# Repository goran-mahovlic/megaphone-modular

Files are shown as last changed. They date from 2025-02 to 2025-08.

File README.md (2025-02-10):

# megaphone-r5-modular
Modularised MEGAphone Design

This project is being carried out with the support of the NLnet Foundation under: https://nlnet.nl/project/MEGA65-MVP/

The goal of this project is to push the MEGAphone forward towards a Minimum Viable Product (MVP) in a cost-effective way by modularising the PCB
allowing for faster development and lower development costs as a result. Also, the modularisation helps to work around supply-chain problems by
allowing the replacement of hard to source components, without requiring a full PCB redesign.  Those modules can also be manufactured much more easily
in a domestic setting, as there is less cumulative chance of messing something up.  Alternatively, they can be manufactured in modest sized batches
using PCB fabrication places like PCBWay, who also offer an assembly option.

The following sections outline the tasks and their current state of progress, where appropriate.

## Task 1: Development and testing of core simple cellular telephony and text messaging software

The software aspect of this project relates to the software required to control and interact with the hardware modules, as well as to perform basic telephony functionality.

## Task 2: Modularisation and testing of the PCB design

The major hardware stream of this project is focused on modularising the MEGAphone PCB, so that the modules can be iterated and/or manufactured independently. This is to support both users self-manufacturing, so that the complexity of the fabrication process can be greatly simplified, as well as to allow for much faster and, including ad-hoc response to future supply chain challenges. 

### 2.1 High-efficiency DC-DC converter module to power the various sub-systems

High-current and high-efficiency modules are required for the main FPGA, cellular modem, auxilliary communications module, LCD panel, and external speaker/bluetooth modules.  It is desirable to come up with a single module that can be reused several times for these purposes.  The cellular modems are likely to be the highest draw item, and according to https://ww1.microchip.com/downloads/en/Appnotes/ANLPS300-APID.pdf, they can draw upto around 2A at 3.3V, which is the voltage we will most likely use, since it allows a common voltage for many of our sub-systems.

It is unlikely that any other device on the system will consume more power than this, so our DC-DC modules need to support 2A.

A further requirement is that it must be buck-boost, as the LiFePO4 cells can go below 3.3V, but when charged are >3.3V.

Some possible parts to consider:

STBBJ3 https://www.st.com/en/power-management/stbb3j.html  (2A in buck mode, i.e., where VIN > 3.3V, but only 800mA in boost mode, i.e., where VIN < 3.3V). 5x4 grid array, without thermal pad. Shutdown and soft-start. "typical" efficiency of 94%
LTC3113 https://www.analog.com/media/en/technical-documentation/data-sheets/3113f.pdf (3A in buck mode, 1.5A in boost mode). "up to" 96% efficiency. Choice of grid array and TSSOP -- but with a concealled thermal pad on the underside, which is not easy to hand-solder. AU$20 each for TTSOP!

### 2.2 Low-energy power-management module to minimise energy consumption of device, especially in low-power modes

### 2.3 Battery management and energy harvesting module to allow USB-C, integrated solar panel and external 12/24V vehicle battery power sources, and efficient management of the integrated rechargeable battery

### 2.4 Cellular modem communications module, including SIM card module

### 2.5 Internal microphone and speaker module

### 2.6 External speaker and bluetooth headset interface module

### 2.7 Primary FPGA carrier module, leveraging off-the-shelf FPGA modules if at all possible

### 2.8 LCD panel interface module

### 2.9 Auxiliary communications module, e.g., LoRa, ultra-sonic, infra-red or mm wave

Low-cost LoRa devices based on the SX1262 look to be an option, using open-source software like this: https://github.com/beegee-tokyo/SX126x-Mesh-Network
The goal would be for the module to be able to autonomously participate in the mesh while the main process is off.  ESP32s can go into low power modes with <1mA consumption according to https://www.arrow.com/en/research-and-events/articles/esp32-power-consumption-can-be-reduced-with-sleep-modes, and the SX1262 uses only about 5mA to listen for packets, and perhaps 70mA when active, so this looks plausible. The SX1262 when transmitting can draw upto about 120mA according to https://semtech.my.salesforce.com/sfc/p/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

Thus the total power consumption of an auxilliary communications module (assuming we include an ESP32 in it, rather than using the power management FPGA to run the mesh) will be about 5mA while idle (~17mW) and upto ~200mA (~660mW).

### 2.10 Main carrier board and assembly, into which the various modules connect

## Task 3: Integration, Integration testing and remediation of the modules

Once the modules have been tested independently, this activity is focussed on testing the behaviour of the modules when connected to one another, including any VHDL/FPGA programming required to achieve this.

### 3.1 Requirements specification and analysis

### 3.2 Hardware integration and testing, including FPGA programming

### 3.3 Software integration and testing

### 3.4 Engage with and respond to security and accessibility audits

### 3.5 Remediation and contingency – for addressing any issues with the software and/or hardware components identified during the integration, and implementing or documenting appropriate solutions and/or work-arounds as appropriate

## Task 4: Preparation of Prototype Units

This activity focuses on taking the integrated hardware and software modules, and building a small number of units that are alpha-quality prototypes.  The specific objective is that they be integrated into units that are suitable for developers to use to continue development of both hardware and software of the system.  These units may be somewhat larger than the final obtainable footprint, depending on the costs of designing and fabricating the housings/enclosures.  The limited budget prevents the engagement of industrial designers who would be required for the completion of design for manufacture. Instead, we anticipate that the enclosures will be relatively simple 3D printed designs.
The remediation budget line is to allow for adjustment to the case design, the fabricated case and/or any of the hardware modules, so that the prototypes can be assembled and be as functional as possible.

### 4.1 Case Design

### 4.2 Case Fabrication

### 4.3 Assembly

### 4.4 Remediation / Mitigation, e.g., of any fitment issues, whether by adjustment of the case, reworking of a module or other means.

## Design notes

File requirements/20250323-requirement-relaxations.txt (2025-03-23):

Relaxation of Requirement 2.1.2: Bluetooth host module support for keyboards and other HID peripherals. Downgrade from REQUIREMENT to DESIRABLE.
Impact: Bluetooth keyboards and other HID devices will not be usable.
Proposed: PGS
Assessed and approved: PGS

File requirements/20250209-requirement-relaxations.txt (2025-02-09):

Relaxation of Requirement 1.2.2.1: Maximum input voltage reduced from 40V to ~28V.
Impact: (1) 24V truck systems may peak out of range when alternator charging. (2) Some larger solar panels may be out of spec. However, given the ~30Wh battery size, this should not be a problem. Impact acceptable.
Proposed: PGS
Assessed and approved: PGS

Relaxation of Requirement 1.2.3.1: Minimum solar panel input voltage increased from 2V to 6V.
Impact: Some very small panels, especially those consisting of few cells in series, no longer in specification.  However, small panels (eg 55x70mm) are readily available with 6V MP voltages. Thus the impact is acceptable.
Proposed: PGS
Assessed and approved: PGS

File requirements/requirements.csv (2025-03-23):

Requirement | Description
Requirement 1.1.1 | "Integrated LiFePO4 or other similarly safe and robust chemistry battery cell."
Requirement 1.1.2 | "Battery capacity and idle power consumption combine to support a battery endurance of at least 1 week when idle."
Requirement 1.1.2.1 | "Integrated battery capacity of at least 30Wh."
Requirement 1.1.2.2 | "Idle power consumption below 175mW."
Requirement 1.2.1.1 | "The internal battery shall be chargeable via an integrated USB-C connector | ideally fast charging."
Requirement 1.2.1.2 | "Define module bay for USB-C charger + data module | large enough to fit the SparkFun module | as that looks to be the biggest | capable of delivering 20V @ 3A to the carrier board."
Requirement 1.2.1.3 | "Proof-of-concept charger module based on a given USB-C power delivery module (no need for data)."
Requirement 1.2.1.4 | "Power isolation mechanism to allow conflict-free operation of the USB-C and alternative power inputs to the MEGAphone (back-flow and over-voltage protection | for example)"
Requirement 1.2.2.1 | "Means of accepting (including connector) dirty DC power between ~9V and ~28V using a MPPT to maximise efficiency with a solar panel. (Varied 20250209)"
Requirement 1.2.3.1 | "Means of accepting DC power from integrated solar panel at input voltages of 6V to 20V with a MPPT. (Varied 20250209)"
Requirement 1.3.1 | "Power management processor that can control power to all other sub-systems | and itself have very low power consumption | ideally <10mW."
Requirement 1.3.2 | "Ability for power management processor to buffer communications when main processor is powered off."
Requirement 1.3.3 | "Galvanic isolation of communications lines between sub-systems that can be independently powered off | e.g. | using opto-isolators."
Requirement 1.3.4 | "A small module for galvanic isolation | so that this can be reused. "
Requirement 1.3.5 | "Implement UART connection between power control processor and the main FPGA via MEGA65 buffered UART interface. "
Requirement 1.3.6 | "Protect writing to the power control UART so that it can be done only from the Hypervisor."
Requirement 1.3.7 | "Implement Hypervisor calls to provide an API for applications to request power to be switched on and off."
Requirement 1.3.8 | "Implement register access to check battery state and charger status (i.e. | charging | discharging | which power source(s) are present)."
Requirement 1.4.1 | "High-efficiency DC switchable DC power supplies that can support various sub-systems with >=2A @ 3.3V or 5V (externally selectable) | with an efficiency of at least 90% in typical conditions when powered from a single cell LiFEPO4 battery (28.V - 3.2V)."
Requirement 1.4.2 | "LCD Panel Backlight power supply module (20V | 50mA | powered from VBAT | switchable via a single enable input pin) | unless incorporated into the solution to Requirement 3.3.1)."
Requirement 2.1.1 | "Bluetooth host module that can connect to headsets and other audio devices. Must support UART or I2C control | and audio interfaces that we can easily implement from the FPGA | such as I2S audio."
Desirable 2.1.2 | "Bluetooth host module support for keyboards and other HID peripherals."
Requirement 2.2.1 | "Cellular Module Carrier board that can accept an industry standard industrial cellular modem | breaking out all pins from the connectors | and provides a SIM card slot."
Requirement 2.2.2 | "Create UART for cellular modem AT command interface to the MEGA65 buffered serial interface. This should keep output from cellular modem in a buffer until the application requests the next line or bunch of bytes | and require acknowledgement each time | to prevent loss of important messages."
Requirement 2.2.3 | "Allow Hypervisor to protect access to the cellular modem UART."
Requirement 2.2.4 | "Create Hypervisor API to request access to the cellular modem."
Requirement 2.3.1 | "Power-switched | galvanically isolated UART interface to a module bay that can accept an alternative communications module"
Requirement 2.3.2 | "A proof-of-concept module for the above that can accommodate some alternative communications module."
Requirement 3.1.1 | "One or more power-switchable MEMS microphones with power status indication."
Requirement 3.2.1 | "Audio CODEC or equivalent that has output channels for loud speaker (mono is ok) | 3.5mm audio output (stereo) ear piece | and input channel for 3.5mm microphone."
Requirement 3.3.1 | "Module to connect to industrial LCD panels of the type used in previous MEGAphone prototypes | large enough to allow for some variability in cable lengths and positions | for both DVGA and touch interface. Allow for either resistive or capacitive interfaces. Include appropriate LCD backlight driver and expose the PWM brightness control signal."
Requirement 3.3.2 | "Module bay to accept the LCD panel module."
Requirement 3.4.1 | "Module hosting a thumb-wheel potentiometer and an I2C potentiometer | with two pins to select I2C address of the module | and pads on the module to add the selection resistors if required."
Requirement 3.4.2 | "Module to accept D-pad"
Requirement 3.4.3 | "Module to accept push-button pairs"
Requirement 3.4.4 | "I2C I/O Expander to accept inputs from buttons and control LEDs"
Requirement 3.4.5 | "Slider switch module for input"
Desirable 3.4.6 | "Module for hosting e-ink display and recessed buttons"
Desirable 3.4.7 | "Module specification for hosting I2C sensors and peripherals"
Requirement 4.1.1 | "A100T or larger FPGA module SWaP and pin-compatible with the Trenz TE0725."
Requirement 4.2.1 | "Module bay that can power and host a FireAnt or similar FPGA module to control the power to all sub-systems | and interdict the communications between the main FPGA and sub-systems that require monitoring when the main FPGA is powerd off."
Desirable 4.3.1 | "Bay for Pi Compute Module 4"
Desirable 4.3.2 | "DVGA multiplexor to allow LCD panel to display either the MEGA65 or Pi display | on a pixel by pixel basis."
Desirable 4.3.3 | "Isolatable USB data connection between cellular modem and Pi."
Desirable 4.3.4 | "UART interface between Pi Compute Module and MEGA65 core."
Requirement 5.1.1 | "Main carrier board that connects all sub-systems together."
Requirement 5.1.2 | "Design a 3D-printable / CNC machinable case to contain the electronics package."
Requirement 6.1.1 | "Power control API on low-power FPGA to allow control of power to all sub-systems | including the main FPGA."
Requirement 6.1.2 | "Logic to activate power to the main FPGA based on relevant criteria (eg incoming call | user pressing power button etc)."
Requirement 6.1.3 | "UART interface between main and low-power FPGA module exposed via one of the MEGA65 buffered UART interfaces."
Requirement 6.1.4 | "MEGA65-side software that implements the power control API."
Requirement 6.2.1 | "Can initiate telephone calls via dialing or selecting a contact."
Requirement 6.2.2 | "Can accept incoming telephone calls | showing contact name when the caller matches an existing contact."
Requirement 6.2.3 | "Can list contacts."
Requirement 6.2.4 | "Can add a contact."
Requirement 6.2.5 | "Can edit a contact."
Requirement 6.2.6 | "Can delete a contact. "
Requirement 6.2.7 | "Incoming calls are indicated | even if the user is performing some other function (e.g. | OSD overlay or blinking LED)."
Requirement 6.3.1 | "Incoming SMS messages are indicated | even if the user is performing some other function (e.g. | OSD overlay or blinking LED)."
Requirement 6.3.2 | "SMS message can be composed and sent to a number or contact."
Requirement 6.3.3 | "SMS message can be received | and the corresponding contact indicated."
Desirable 6.3.4 | "SMS messages are logged | so that SMS conversation threads can be displayed."

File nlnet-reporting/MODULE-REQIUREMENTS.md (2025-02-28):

# Summary of Progress

During this tranch of activity, the full requirements for the MEGAphone Modular were derived and documented.
The derivation of the requirements can be found in this blog post:

https://c65gs.blogspot.com/2025/02/modular-megaphone-requirement.html

A collated table of the requirements can be found here:

https://github.com/MEGA65/megaphone-modular/blob/main/requirements/requirements.csv

# System Requirements Mapping to NLNet Milestones

For the specific requirements specification milestones claimed, the mapping between those milestones and the derived requirements is summarised below.

Note that for some modules, the requirements have ended up being quite short and succinct. This is a positive feature, enabled by the substantial work undertaken to understand the system, decompose it sensibly, and then distill the actual requirements (including a few desirable characteristics) of the system.

| NLnet Milestone | Requirement(s) of Relevance |
| --- | --- |
| 2.1.1 High-efficiency DC-DC converter module to power the various sub-systems | [1.4.1](https://github.com/MEGA65/megaphone-modular/blob/main/requirements/requirements.csv#L20) |
| 2.2.1 Low-energy power-management module to minimise energy consumption of device, especially in low-power modes | [1.1.2](https://github.com/MEGA65/megaphone-modular/blob/main/requirements/requirements.csv#L3), [1.1.2.2](https://github.com/MEGA65/megaphone-modular/blob/main/requirements/requirements.csv#L5), [4.2.1](https://github.com/MEGA65/megaphone-modular/blob/main/requirements/requirements.csv#L44), [6.1.1](https://github.com/MEGA65/megaphone-modular/blob/main/requirements/requirements.csv#L50), [6.1.3](https://github.com/MEGA65/megaphone-modular/blob/main/requirements/requirements.csv#L52) |
| 2.3.1 Battery management and energy harvesting module to allow USB-C, integrated solar panel and external 12/24V vehicle battery power sources, and efficient management of the integrated rechargeable battery | [1.2.1.1](https://github.com/MEGA65/megaphone-modular/blob/main/requirements/requirements.csv#L6), [1.2.1.2](https://github.com/MEGA65/megaphone-modular/blob/main/requirements/requirements.csv#L7), [1.2.1.3](https://github.com/MEGA65/megaphone-modular/blob/main/requirements/requirements.csv#L8), [1.2.1.4](https://github.com/MEGA65/megaphone-modular/blob/main/requirements/requirements.csv#L9), [1.2.2.1](https://github.com/MEGA65/megaphone-modular/blob/main/requirements/requirements.csv#L10), [1.2.3.1](https://github.com/MEGA65/megaphone-modular/blob/main/requirements/requirements.csv#L11), [1.3.1](https://github.com/MEGA65/megaphone-modular/blob/main/requirements/requirements.csv#L12), [1.3.2](https://github.com/MEGA65/megaphone-modular/blob/main/requirements/requirements.csv#L13) |
| 2.4.1 Cellular modem communications module, including SIM card module | [2.2.1](https://github.com/MEGA65/megaphone-modular/blob/main/requirements/requirements.csv#L26) |
| 2.5.1 Internal microphone and speaker module | [3.1.1](https://github.com/MEGA65/megaphone-modular/blob/main/requirements/requirements.csv#L31), [3.2.1](https://github.com/MEGA65/megaphone-modular/blob/main/requirements/requirements.csv#L32) |
| 2.6.1 External speaker and bluetooth headset interface module | [2.1.1](https://github.com/MEGA65/megaphone-modular/blob/main/requirements/requirements.csv#L24), [2.1.2](https://github.com/MEGA65/megaphone-modular/blob/main/requirements/requirements.csv#L25) |
| 2.7.1 Primary FPGA carrier module, leveraging off-the-shelf FPGA modules if at all possible | [4.1.1](https://github.com/MEGA65/megaphone-modular/blob/main/requirements/requirements.csv#L43) |
| 2.8.1 LCD panel interface module | [1.4.2](https://github.com/MEGA65/megaphone-modular/blob/main/requirements/requirements.csv#L21), [3.3.1](https://github.com/MEGA65/megaphone-modular/blob/main/requirements/requirements.csv#L33), [3.3.2](https://github.com/MEGA65/megaphone-modular/blob/main/requirements/requirements.csv#L34) |
| 2.9.1 Auxiliary communications module, e.g., LoRa, ultra-sonic, infra-red or mm wave: Requirement Specification | [2.3.1](https://github.com/MEGA65/megaphone-modular/blob/main/requirements/requirements.csv#L28), [2.3.2](https://github.com/MEGA65/megaphone-modular/blob/main/requirements/requirements.csv#L29) |
| 2.10.1 Main carrier board and assembly, into which the various modules connect | [3.2.1](https://github.com/MEGA65/megaphone-modular/blob/main/requirements/requirements.csv#L32), [3.4.2](https://github.com/MEGA65/megaphone-modular/blob/main/requirements/requirements.csv#L36), [3.4.3](https://github.com/MEGA65/megaphone-modular/blob/main/requirements/requirements.csv#L37), [3.4.4](https://github.com/MEGA65/megaphone-modular/blob/main/requirements/requirements.csv#L38), [3.4.5](https://github.com/MEGA65/megaphone-modular/blob/main/requirements/requirements.csv#L39), [3.4.7](https://github.com/MEGA65/megaphone-modular/blob/main/requirements/requirements.csv#L41), [5.1.1](https://github.com/MEGA65/megaphone-modular/blob/main/requirements/requirements.csv#L45) |

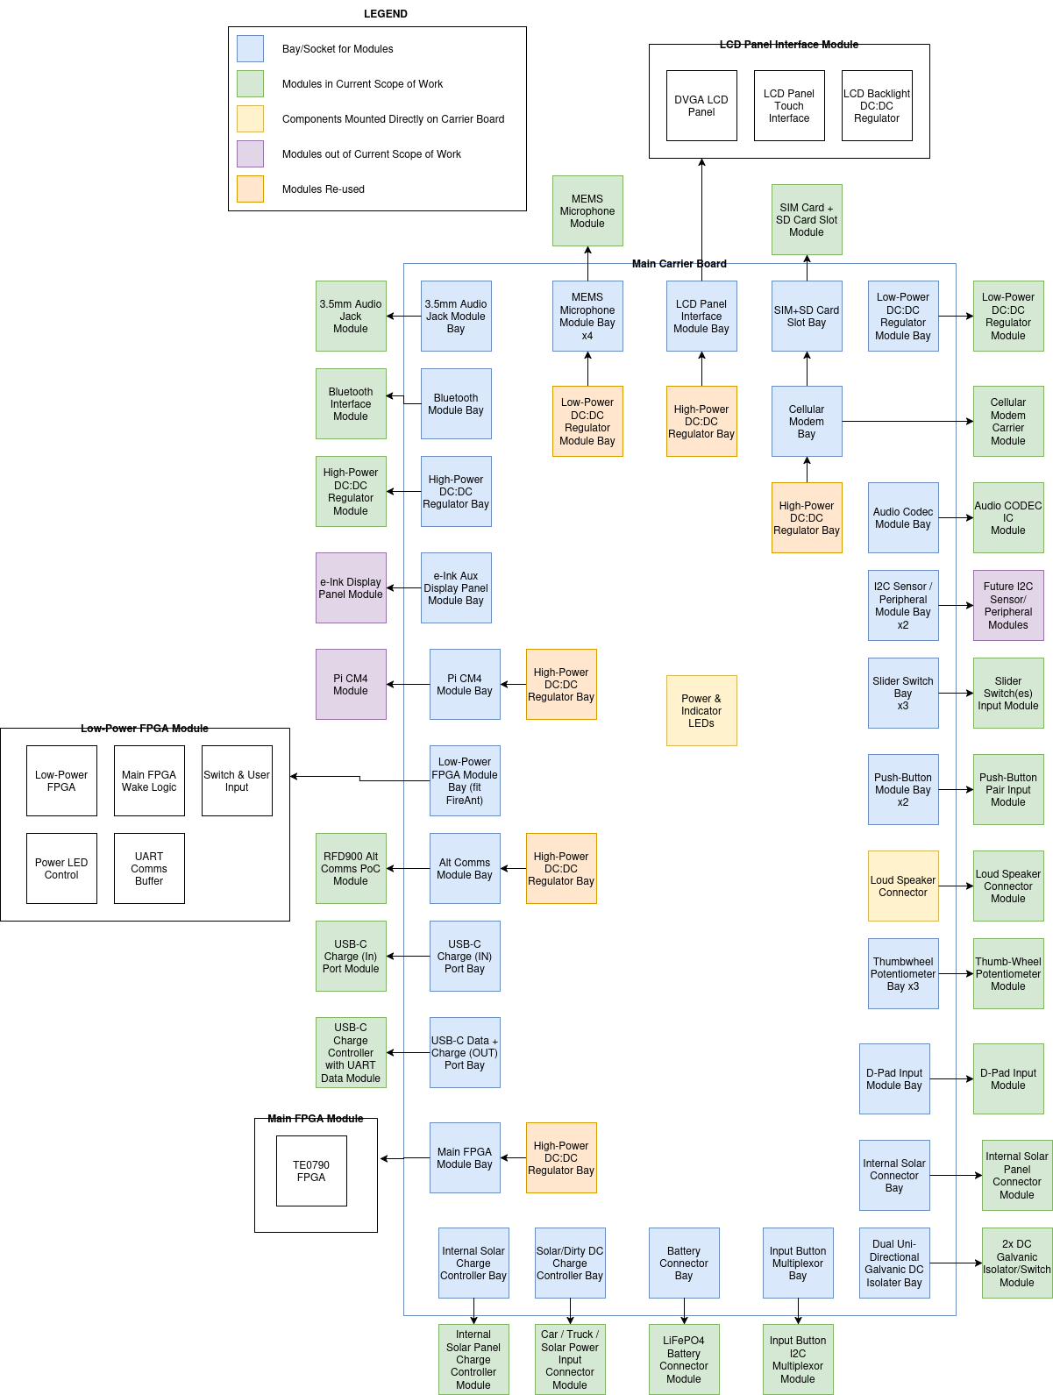
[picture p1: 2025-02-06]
diagrams/modular-megaphone-block-diagram.drawio.png

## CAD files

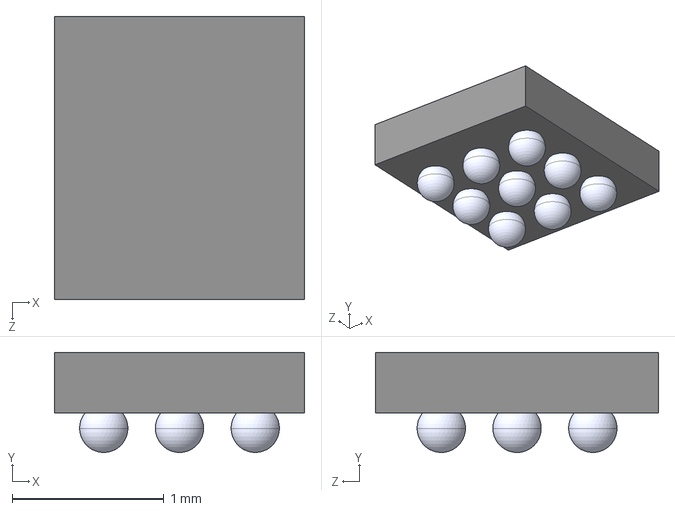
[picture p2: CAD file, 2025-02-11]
modules/audio-codec/ADP5301ACBZ-1-R7.step
1.65 x 0.66 x 1.87 mm

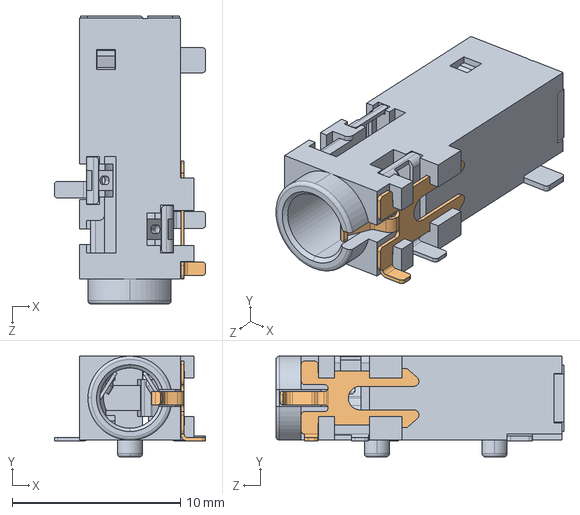
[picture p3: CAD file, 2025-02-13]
modules/audio-jack/SJ-43514-SMT-TR.step
9.00 x 6.00 x 17.1 mm

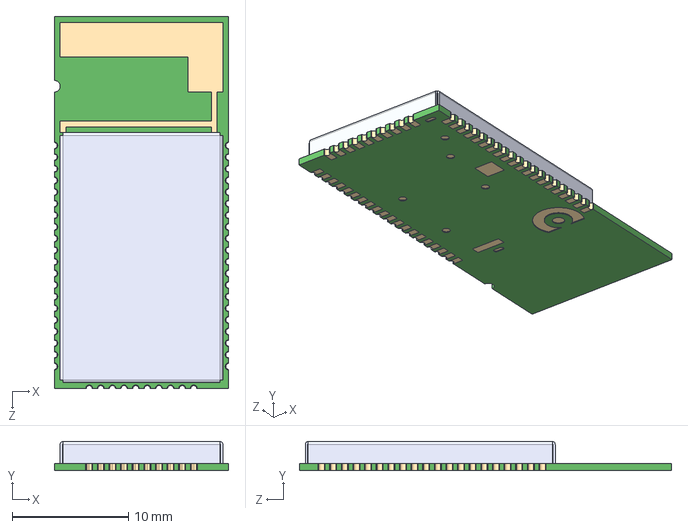
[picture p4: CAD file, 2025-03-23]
modules/bluetooth/footprints/BM83SM1-00AA.step
15.0 x 2.50 x 32.0 mm

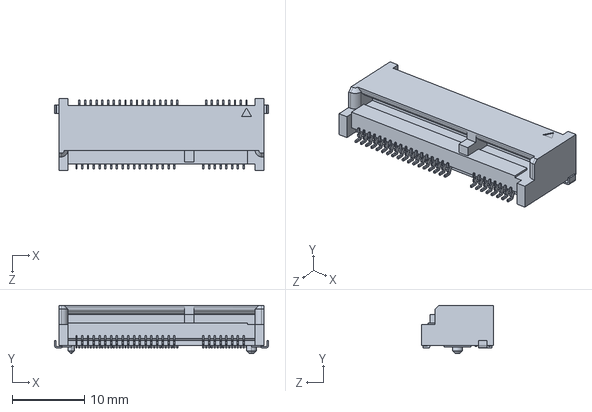
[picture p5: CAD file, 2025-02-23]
modules/cellular-modem/MM60-52B1-E1-R2 JAE Connector Division Proprietary.step
29.7 x 6.70 x 10.0 mm

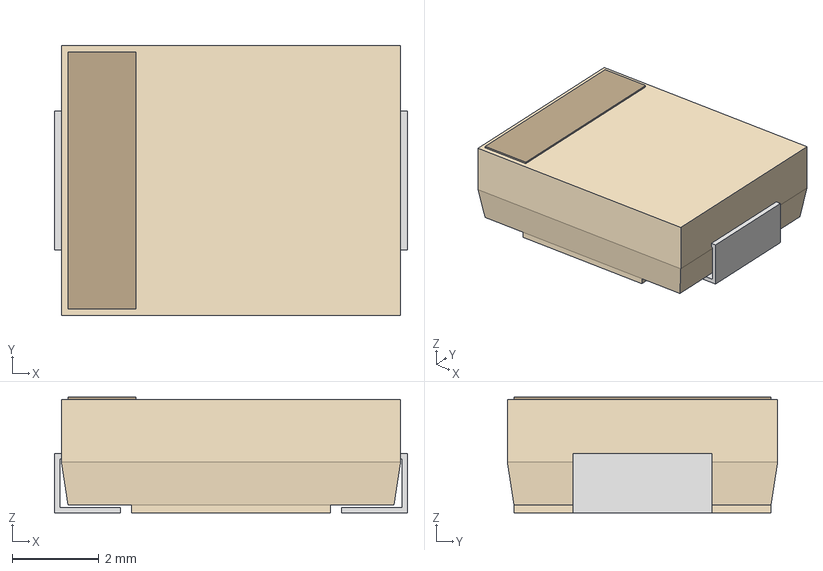
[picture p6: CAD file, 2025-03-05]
modules/input-power-selector/footprints/SMCJSeries_LTF.step
8.13 x 6.22 x 2.67 mm

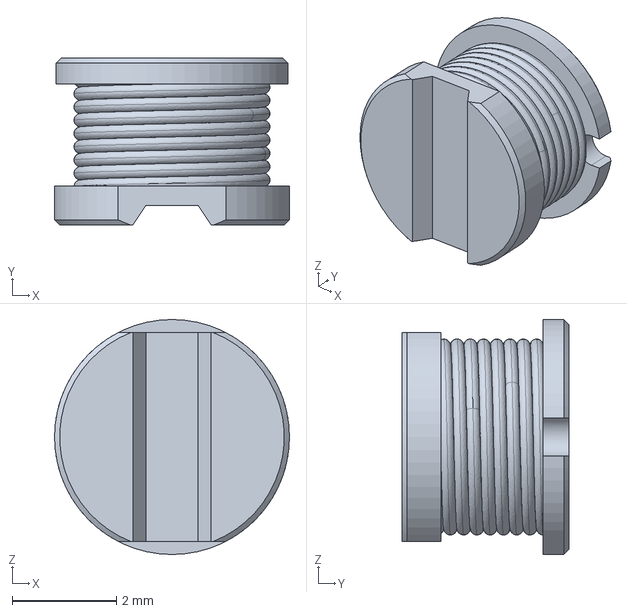
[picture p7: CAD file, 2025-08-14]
modules/lcd-panel/SDR0403-4R7ML.stp
4.50 x 3.20 x 4.50 mm

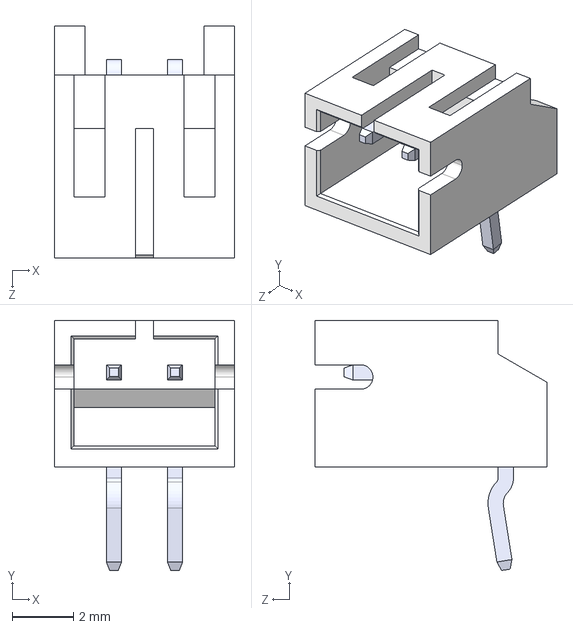
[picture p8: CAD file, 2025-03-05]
modules/solar-and-dc-connectors/footprints/S2B-PH-K-S.STEP
5.90 x 8.18 x 7.60 mm

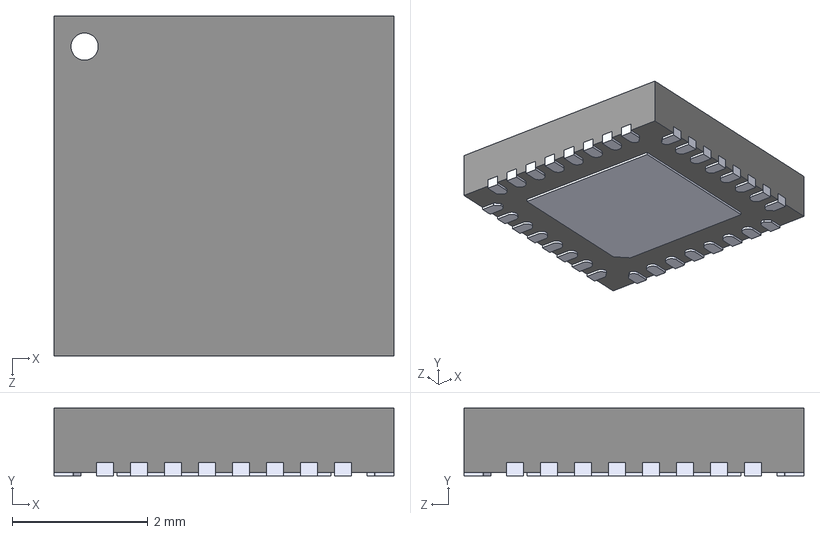
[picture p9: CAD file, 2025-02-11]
modules/audio-codec/TLV320AIC3110IRHBR.step
5.00 x 1.00 x 5.00 mm

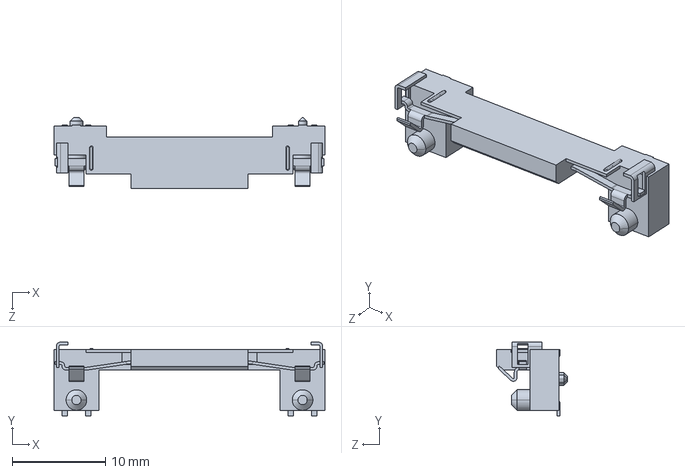
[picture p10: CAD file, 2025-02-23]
modules/cellular-modem/MM60-EZH059-B5-R2 JAE Connector Division Proprietary.step
29.0 x 7.90 x 7.60 mm

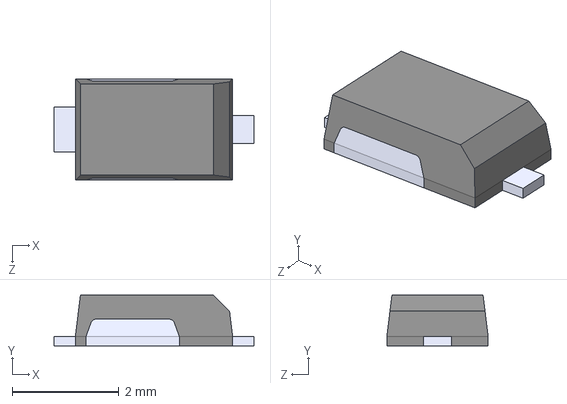
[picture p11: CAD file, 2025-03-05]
modules/input-power-selector/footprints/SMM4F24A-TR.step
3.75 x 0.95 x 1.90 mm

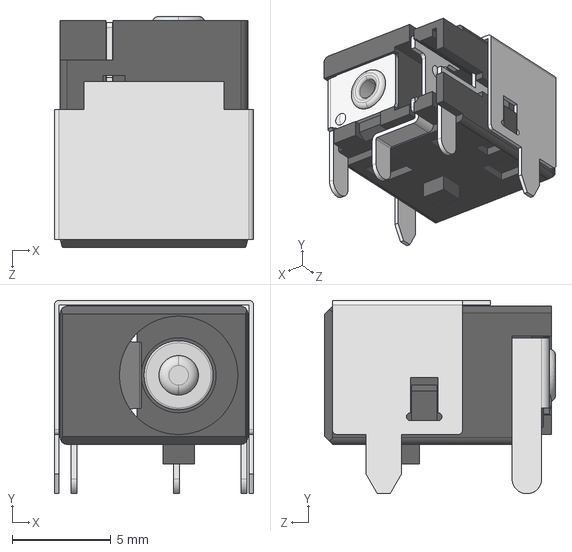
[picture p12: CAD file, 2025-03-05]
modules/solar-and-dc-connectors/footprints/54-00127.step
10.1 x 9.80 x 11.7 mm

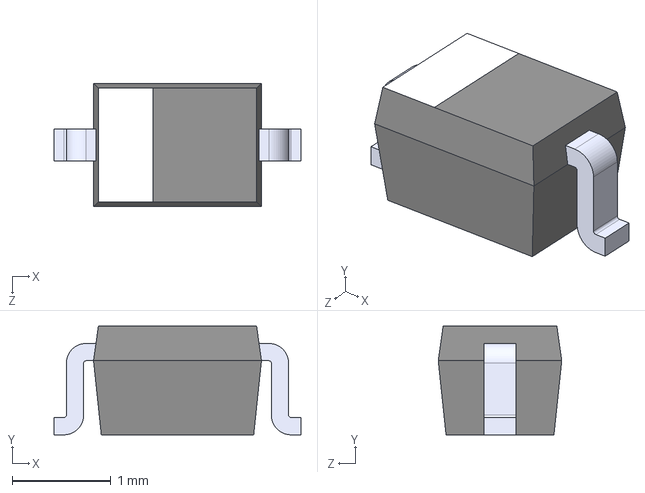
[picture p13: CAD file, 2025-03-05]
modules/input-power-selector/footprints/BZX384-C30_115.step
2.50 x 1.10 x 1.25 mm

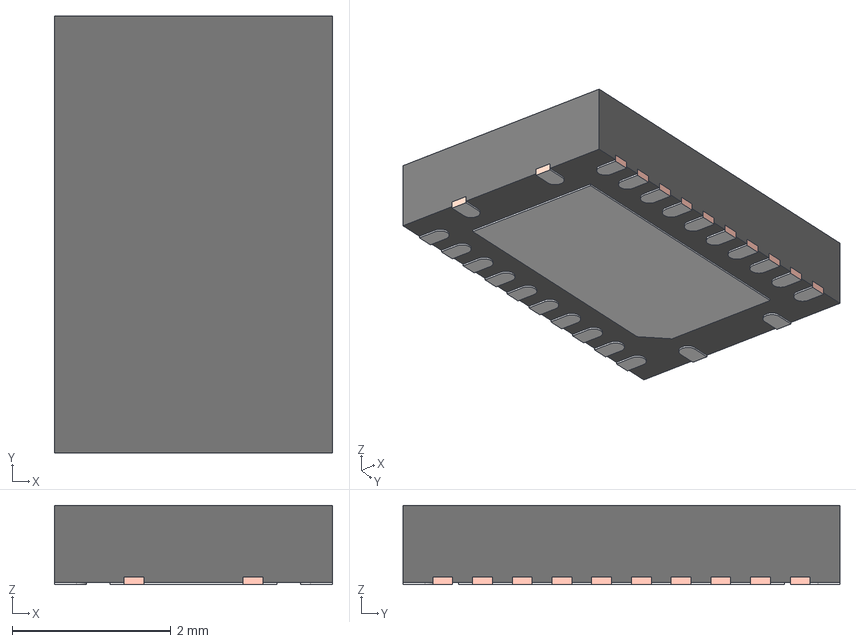
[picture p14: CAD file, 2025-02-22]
modules/cellular-modem/RGY0024F.stp
3.50 x 5.50 x 1.00 mm
FRAME
PIN1_AREA

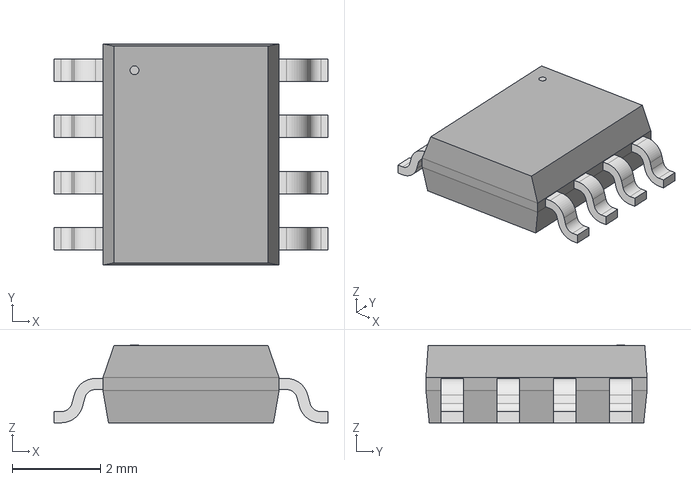
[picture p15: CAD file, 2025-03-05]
modules/input-power-selector/footprints/SOIC_09DY-T1-GE3_VIS.step
6.20 x 5.00 x 1.75 mm

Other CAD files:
modules/lcd-panel/RTW0024A.stp
modules/input-power-selector/footprints/PowerPAK_8x8L_BWL-2_VIS.step
modules/input-power-selector/footprints/IPF067N20NM6ATMA1.stp
modules/input-power-selector/footprints/TSM4800N15CX6RFG.STEP
modules/battery-connector/footprints/691210910002.step
modules/cellular-modem/TPS631000DRLR.step
modules/input-power-selector/footprints/TSM4800N15CX6RFG.step
modules/lcd-panel/5051100692.stp
modules/lcd-panel/5051104091.stp
modules/sim-and-sd-card/104168-1616.stp

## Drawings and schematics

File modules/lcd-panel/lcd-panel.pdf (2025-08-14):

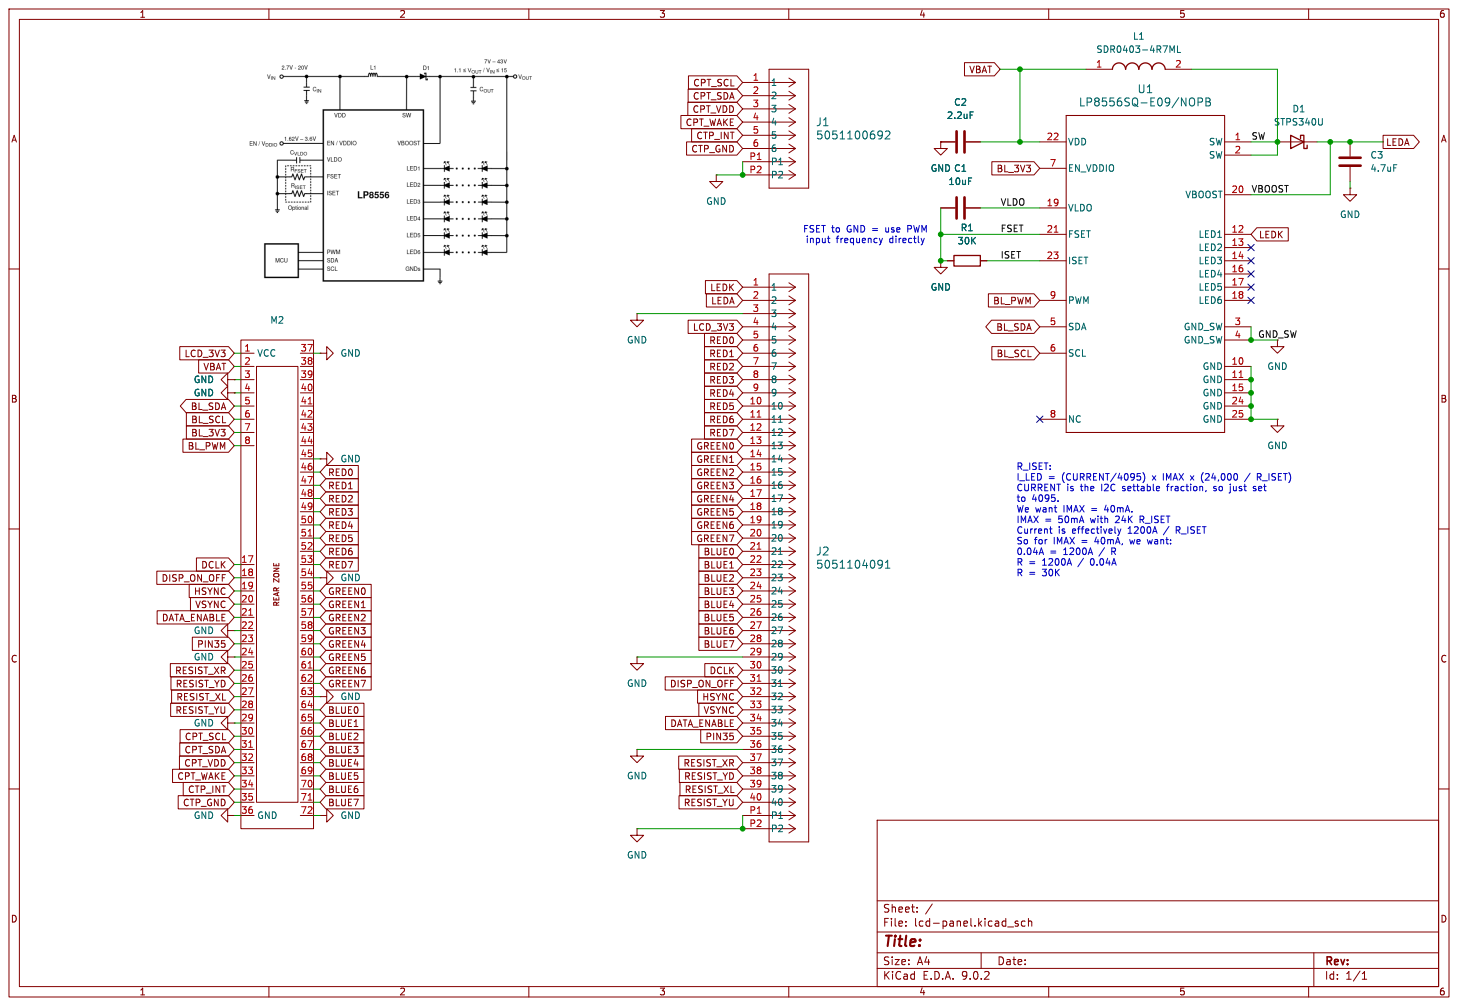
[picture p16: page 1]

FSET to GND = use PWM

to 4095. We want IMAX = 40mA.

18 | 54
19 | 55
20 | 56
21 | 57
22 | 58
23 | 59
24 | 60
25 | 61
26 | 62
27 | 63
28 | 64
29 | 65
30 | 66
31 | 67
32 | 68
33 | 69
34 | 70
35 GND 36 | 71

Id: 1/1 Title: File: lcd-panel.kicad_sch Sheet: /

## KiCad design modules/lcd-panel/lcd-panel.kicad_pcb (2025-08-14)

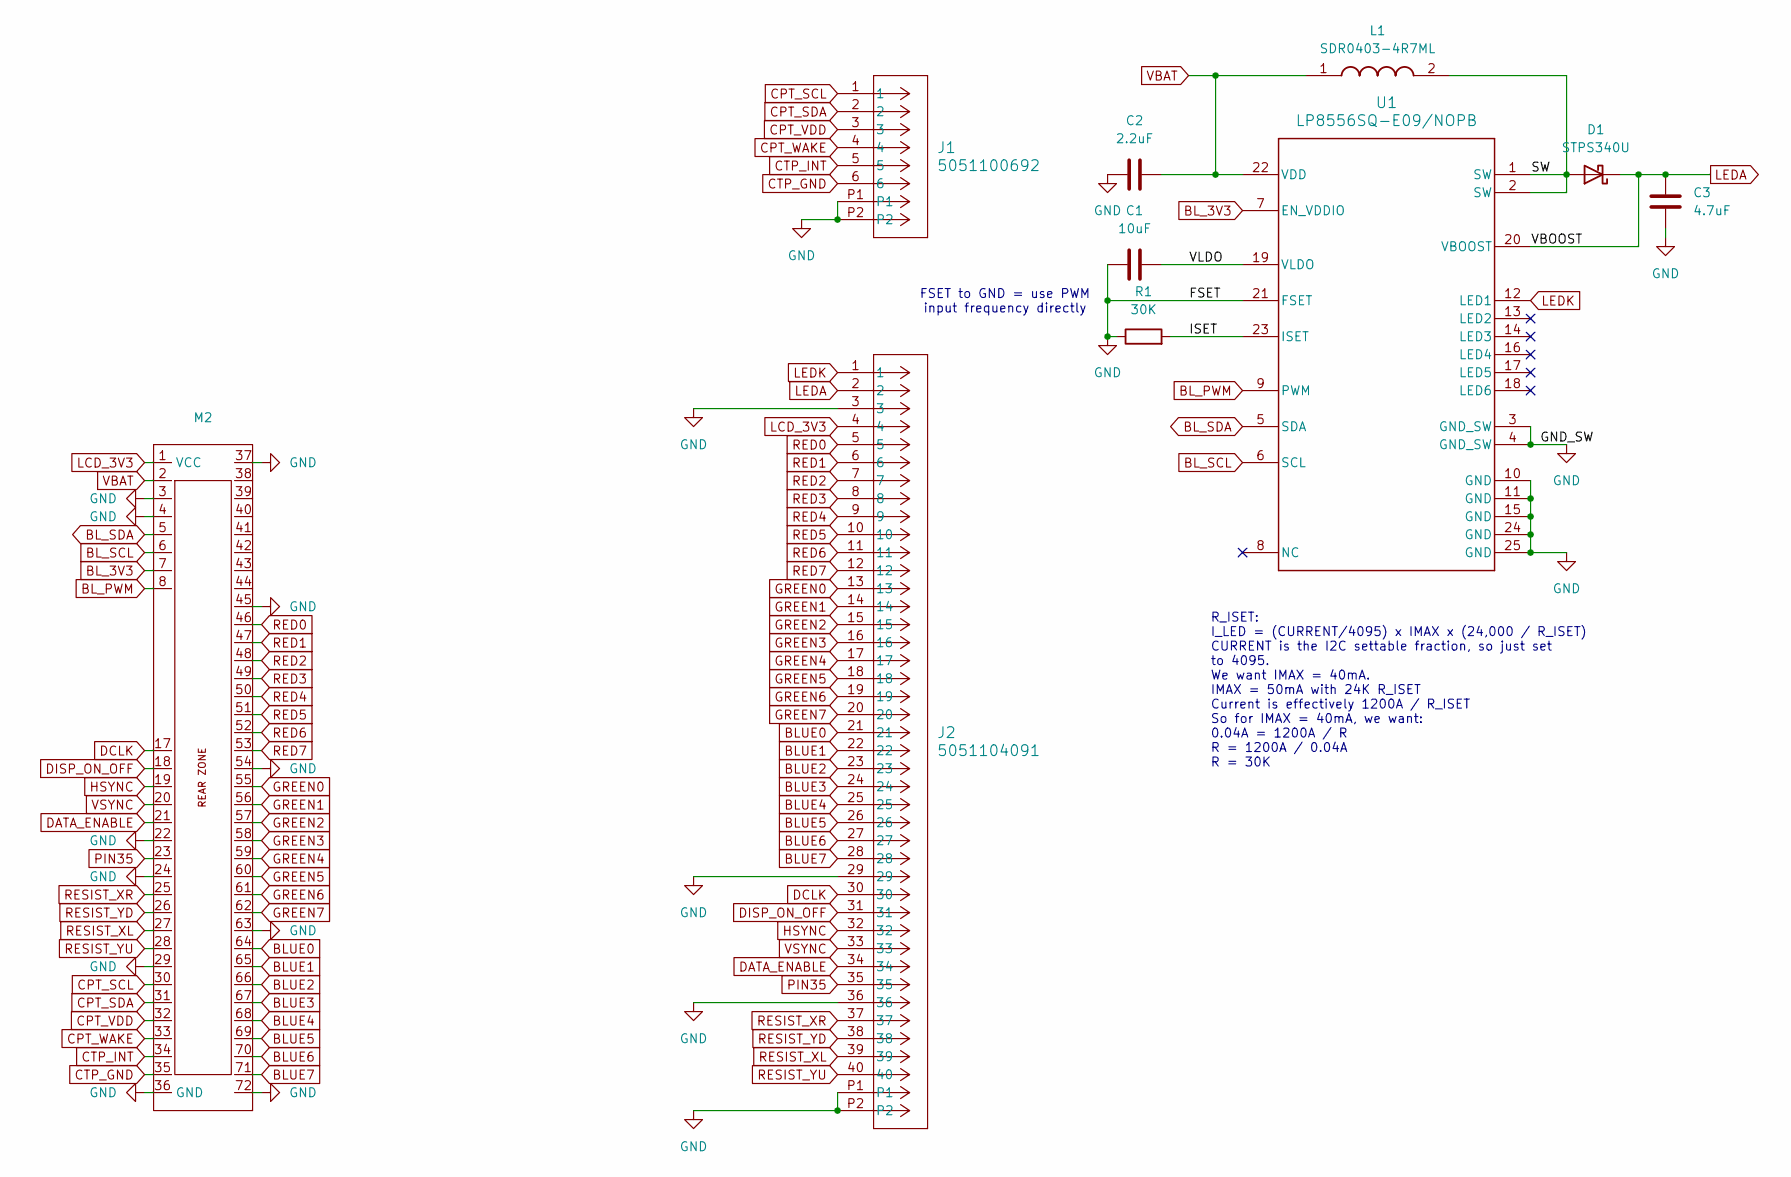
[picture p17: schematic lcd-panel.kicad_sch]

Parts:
C1: 10uF; C_0603_1608Metric_Pad1.08x0.95mm_HandSolder
C2: 2.2uF; C_0603_1608Metric_Pad1.08x0.95mm_HandSolder
C3: 4.7uF; C_0603_1608Metric_Pad1.08x0.95mm_HandSolder
D1: STPS340U; D_SOD-123
J1: 5051100692; CON_5051100692_MOL
J2: 5051104091; CON_5051104091_MOL
L1: SDR0403-4R7ML; SDR0403; Mouser Part Number 652-SDR0403-4R7ML
M2: MegaCastle2x36-Module-I40.0x86.6-MFFFFFFFFFFFFFF-SPAREPAD
R1: 30K; R_0603_1608Metric_Pad0.98x0.95mm_HandSolder
U1: LP8556SQ-E09/NOPB; RTW0024A

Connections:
/ISET: R1.2, U1.23 (ISET)
/SW: D1.2 (A), L1.2, U1.1 (SW), U1.2 (SW)
/VLDO: C1.2, U1.19 (VLDO)
BLUE0: J2.21, M2.64
BLUE1: J2.22, M2.65
BLUE2: J2.23, M2.66
BLUE3: J2.24, M2.67
BLUE4: J2.25, M2.68
BLUE5: J2.26, M2.69
BLUE6: J2.27, M2.70
BLUE7: J2.28, M2.71
BL_3V3: M2.7, U1.7 (EN_VDDIO)
BL_PWM: M2.8, U1.9 (PWM)
BL_SCL: M2.6, U1.6 (SCL)
BL_SDA: M2.5, U1.5 (SDA)
CPT_SCL: J1.1, M2.30
CPT_SDA: J1.2, M2.31
CPT_VDD: J1.3, M2.32
CPT_WAKE: J1.4, M2.33
CTP_GND: J1.6, M2.35
CTP_INT: J1.5, M2.34
DATA_ENABLE: J2.34, M2.21
DCLK: J2.30, M2.17
DISP_ON_OFF: J2.31, M2.18
GND: C1.1, C2.1, C3.2, J1.P1, J1.P2, J2.3, J2.29, J2.36, J2.P1, J2.P2, M2.3, M2.4, M2.22, M2.24, M2.29, M2.36 (GND), M2.37, M2.45, M2.54, M2.63, M2.72, R1.1, U1.3 (GND_SW), U1.4 (GND_SW), U1.10 (GND), U1.11 (GND), U1.15 (GND), U1.21 (FSET), U1.24 (GND), U1.25 (GND)
GREEN0: J2.13, M2.55
GREEN1: J2.14, M2.56
GREEN2: J2.15, M2.57
GREEN3: J2.16, M2.58
GREEN4: J2.17, M2.59
GREEN5: J2.18, M2.60
GREEN6: J2.19, M2.61
GREEN7: J2.20, M2.62
HSYNC: J2.32, M2.19
LCD_3V3: J2.4, M2.1 (VCC)
LEDA: C3.1, D1.1 (K), J2.2, U1.20 (VBOOST)
LEDK: J2.1, U1.12 (LED1)
PIN35: J2.35, M2.23
RED0: J2.5, M2.46
RED1: J2.6, M2.47
RED2: J2.7, M2.48
RED3: J2.8, M2.49
RED4: J2.9, M2.50
RED5: J2.10, M2.51
RED6: J2.11, M2.52
RED7: J2.12, M2.53
RESIST_XL: J2.39, M2.27
RESIST_XR: J2.37, M2.25
RESIST_YD: J2.38, M2.26
RESIST_YU: J2.40, M2.28
VBAT: C2.2, L1.1, M2.2, U1.22 (VDD)
VSYNC: J2.33, M2.20

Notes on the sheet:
FSET to GND = use PWM input frequency directly
R_ISET: I_LED = (CURRENT/4095) x IMAX x (24,000 / R_ISET) CURRENT is the I2C settable fraction, so just set to 4095. We want IMAX = 40mA. IMAX = 50mA with 24K R_ISET Current is effectively 1200A / R_ISET So for IMAX = 40mA, we want: 0.04A = 1200A / R R = 1200A / 0.04A R = 30K

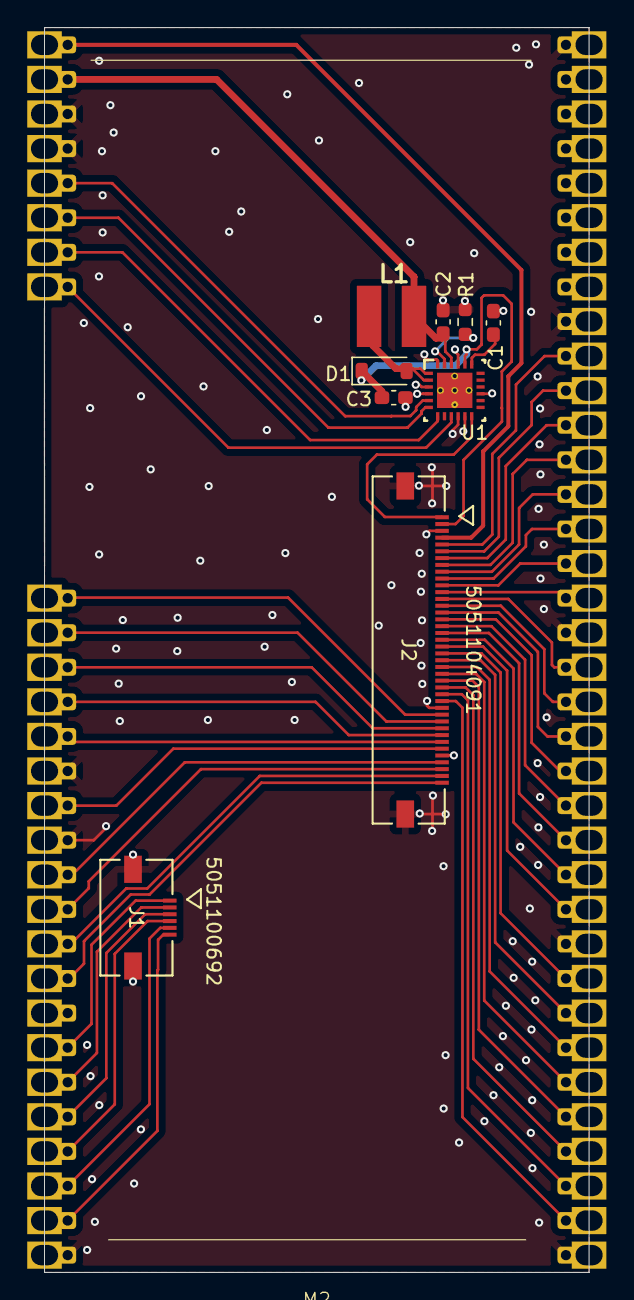
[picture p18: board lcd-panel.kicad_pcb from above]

Board: 4 copper layers, 40.0 x 91.4 mm, 10 parts (0 on the bottom side), 52 nets.

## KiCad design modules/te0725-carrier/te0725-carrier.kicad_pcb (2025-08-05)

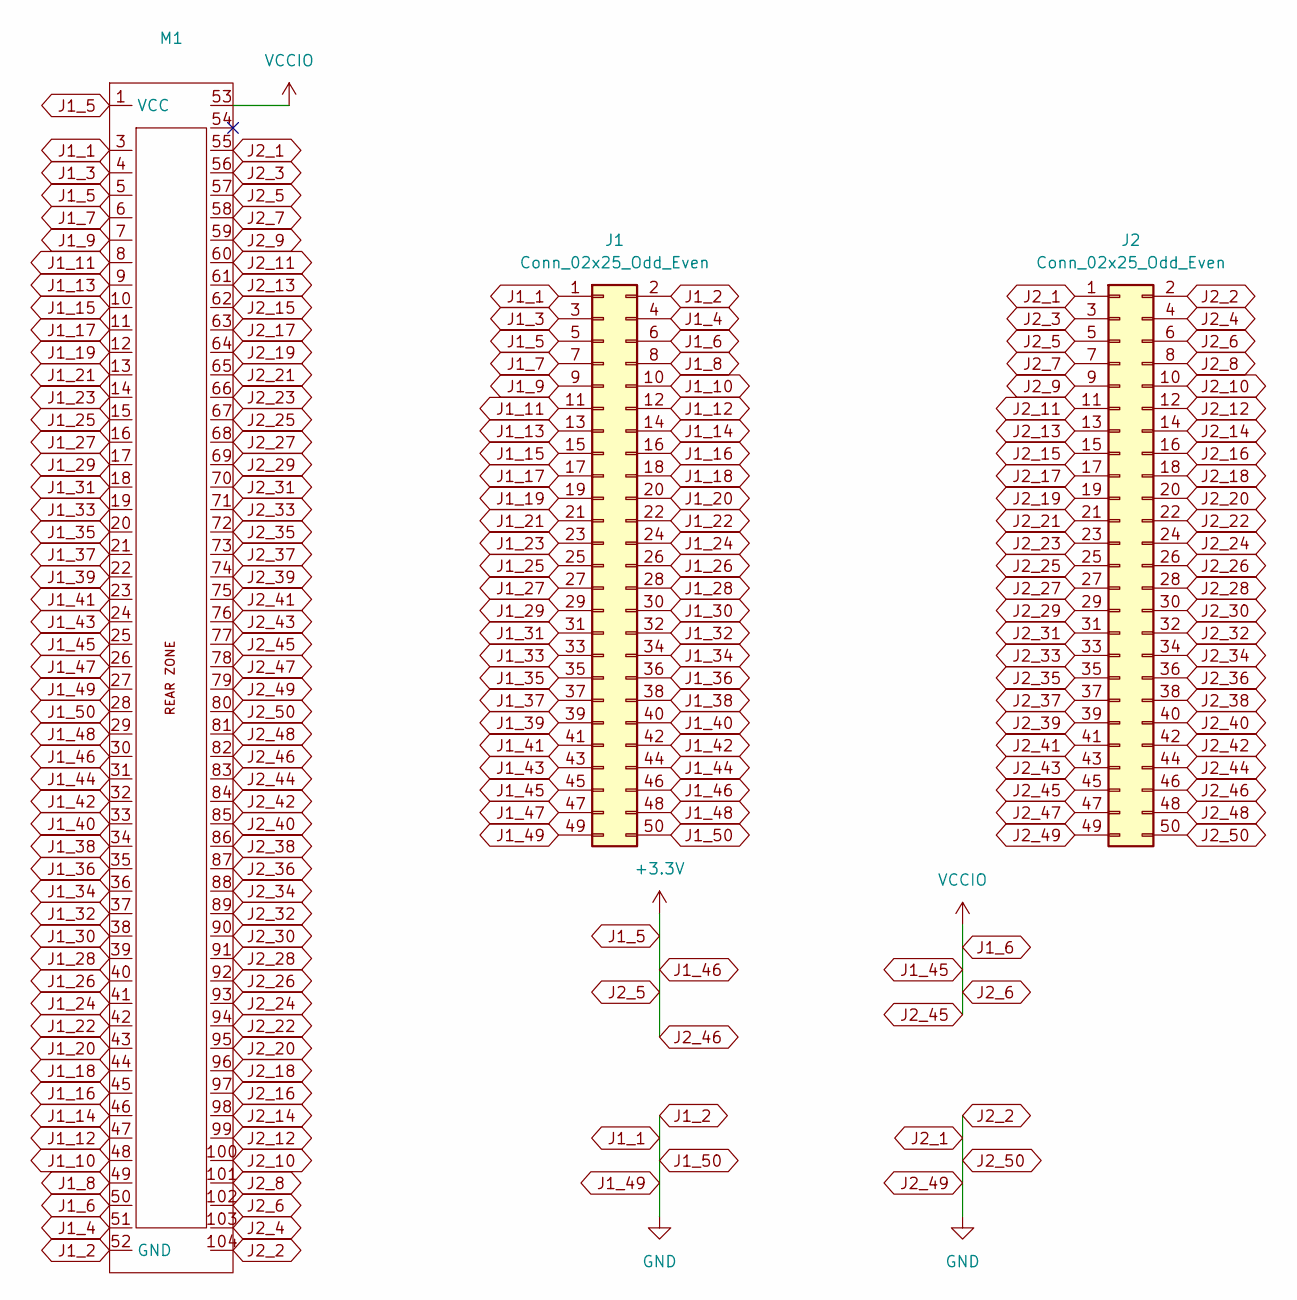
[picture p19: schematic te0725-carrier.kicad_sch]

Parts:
J1, J2: Conn_02x25_Odd_Even; PinHeader_2x25_P2.54mm_Vertical
M1: MegaCastle2x52-Module-I42.0x127.3-M1

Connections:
J1_1: J1.1, J1.2, J1.49, J1.50, J2.1, J2.2, J2.49, J2.50, M1.3, M1.27, M1.28, M1.52 (GND), M1.55, M1.79, M1.80, M1.104
J1_3: J1.3, M1.4
J1_4: J1.4, M1.51
J1_7: J1.7, M1.6
J1_8: J1.8, M1.49
J1_9: J1.9, M1.7
J1_10: J1.10, M1.48
J1_11: J1.11, M1.8
J1_12: J1.12, M1.47
J1_13: J1.13, M1.9
J1_14: J1.14, M1.46
J1_15: J1.15, M1.10
J1_16: J1.16, M1.45
J1_17: J1.17, M1.11
J1_18: J1.18, M1.44
J1_19: J1.19, M1.12
J1_20: J1.20, M1.43
J1_21: J1.21, M1.13
J1_22: J1.22, M1.42
J1_23: J1.23, M1.14
J1_24: J1.24, M1.41
J1_25: J1.25, M1.15
J1_26: J1.26, M1.40
J1_27: J1.27, M1.16
J1_28: J1.28, M1.39
J1_29: J1.29, M1.17
J1_30: J1.30, M1.38
J1_31: J1.31, M1.18
J1_32: J1.32, M1.37
J1_33: J1.33, M1.19
J1_34: J1.34, M1.36
J1_35: J1.35, M1.20
J1_36: J1.36, M1.35
J1_37: J1.37, M1.21
J1_38: J1.38, M1.34
J1_39: J1.39, M1.22
J1_40: J1.40, M1.33
J1_41: J1.41, M1.23
J1_42: J1.42, M1.32
J1_43: J1.43, M1.24
J1_44: J1.44, M1.31
J1_45: J1.6, J1.45, J2.6, J2.45, M1.25, M1.50, M1.53, M1.77, M1.102
J1_46: J1.5, J1.46, J2.5, J2.46, M1.1 (VCC), M1.5, M1.30, M1.57, M1.82
J1_47: J1.47, M1.26
J1_48: J1.48, M1.29
J2_3: J2.3, M1.56
J2_4: J2.4, M1.103
J2_7: J2.7, M1.58
J2_8: J2.8, M1.101
J2_9: J2.9, M1.59
J2_10: J2.10, M1.100
J2_11: J2.11, M1.60
J2_12: J2.12, M1.99
J2_13: J2.13, M1.61
J2_14: J2.14, M1.98
J2_15: J2.15, M1.62
J2_16: J2.16, M1.97
J2_17: J2.17, M1.63
J2_18: J2.18, M1.96
J2_19: J2.19, M1.64
J2_20: J2.20, M1.95
J2_21: J2.21, M1.65
J2_22: J2.22, M1.94
J2_23: J2.23, M1.66
J2_24: J2.24, M1.93
J2_25: J2.25, M1.67
J2_26: J2.26, M1.92
J2_27: J2.27, M1.68
J2_28: J2.28, M1.91
J2_29: J2.29, M1.69
J2_30: J2.30, M1.90
J2_31: J2.31, M1.70
J2_32: J2.32, M1.89
J2_33: J2.33, M1.71
J2_34: J2.34, M1.88
J2_35: J2.35, M1.72
J2_36: J2.36, M1.87
J2_37: J2.37, M1.73
J2_38: J2.38, M1.86
J2_39: J2.39, M1.74
J2_40: J2.40, M1.85
J2_41: J2.41, M1.75
J2_42: J2.42, M1.84
J2_43: J2.43, M1.76
J2_44: J2.44, M1.83
J2_47: J2.47, M1.78
J2_48: J2.48, M1.81

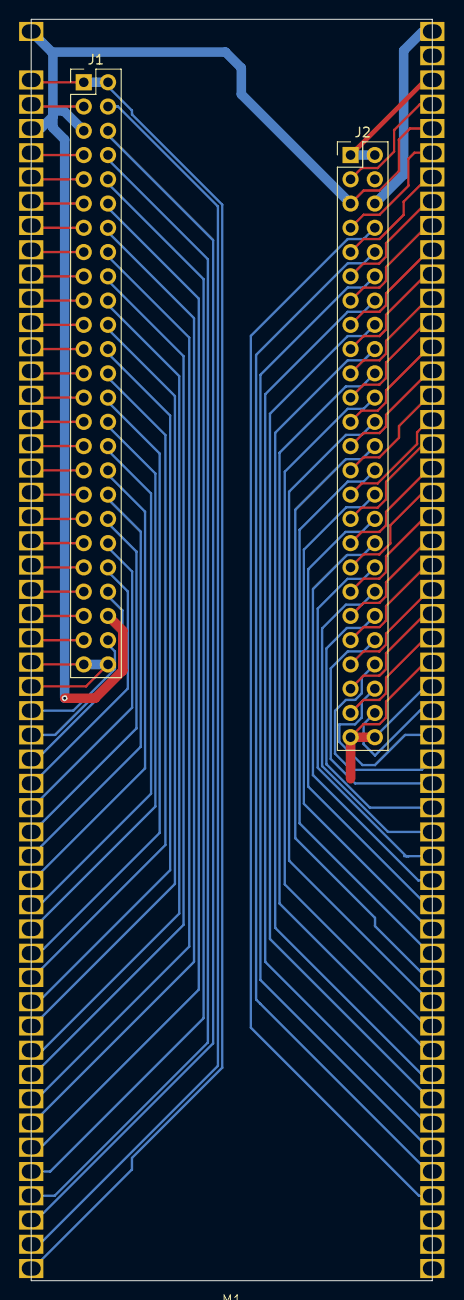
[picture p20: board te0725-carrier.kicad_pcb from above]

Board: 2 copper layers, 42.0 x 132.1 mm, 3 parts (0 on the bottom side), 87 nets.

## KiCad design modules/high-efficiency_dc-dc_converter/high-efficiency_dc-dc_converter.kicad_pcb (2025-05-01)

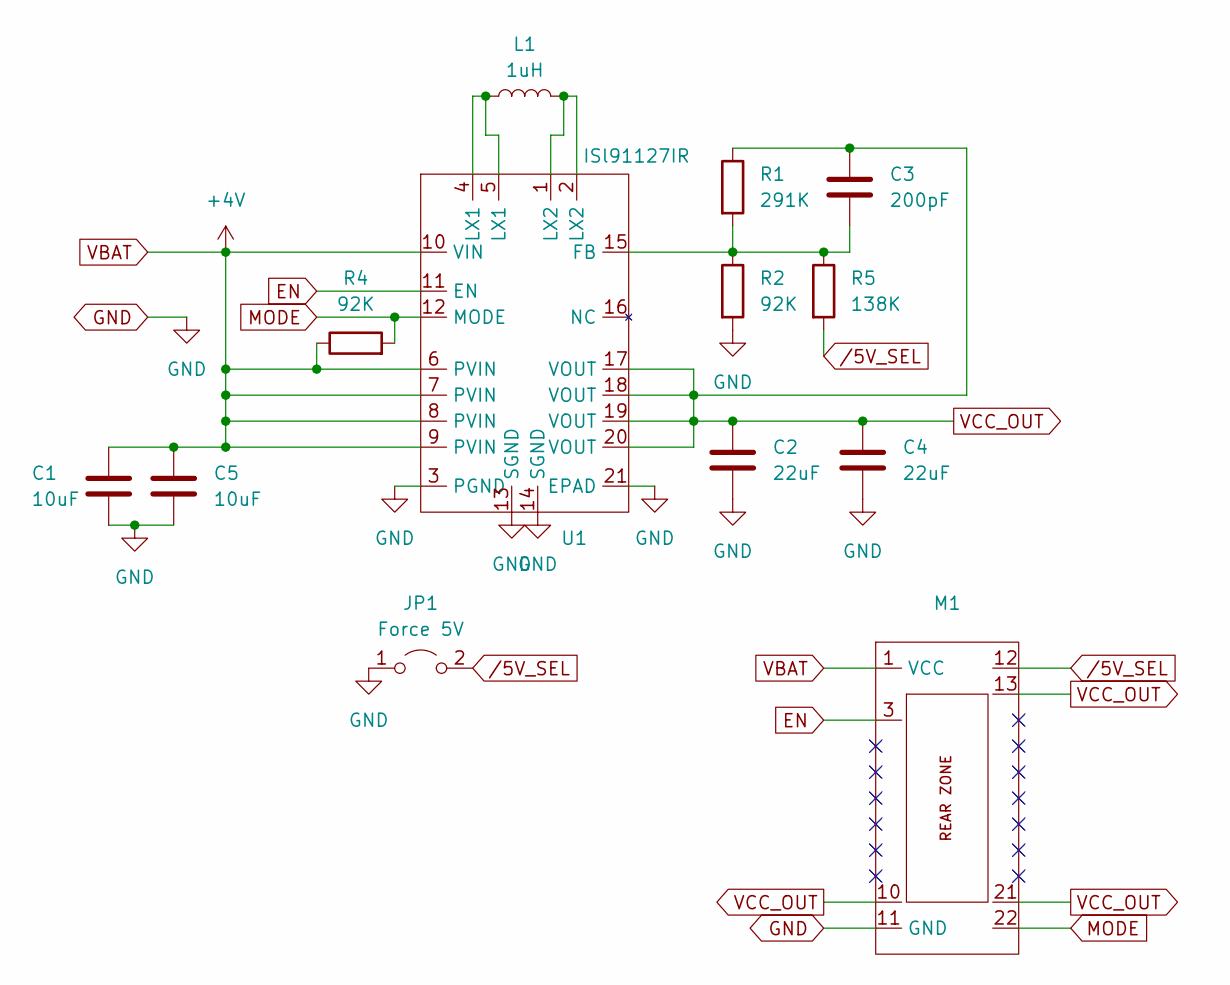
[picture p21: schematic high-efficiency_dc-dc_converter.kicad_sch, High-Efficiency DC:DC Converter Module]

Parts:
C1, C5: 10uF; C_0805_2012Metric; Mouser PN 187-CL21A106KOQNNNG
C2, C4: 22uF; C_0805_2012Metric; Mouser PN 187-CL21A226KOQNNNG
C3: 200pF; C_0805_2012Metric; Mouser 603-CC805JRNPO9BN201
JP1: Force 5V; SolderJumper-2_P1.3mm_Open_RoundedPad1.0x1.5mm
L1: 1uH; L_1008_2520Metric; Mouser PN 81-DFE252012P-1R0MP2
M1: MegaCastle2x11-Module-I15.7x23.1-MA0780C-SPAREPAD
R1: 291K; R_0603_1608Metric
R2, R4: 92K; R_0603_1608Metric; Mouser PN 603-RC0603FR-0791KL
R5: 138K; R_0603_1608Metric; Mouser PN 660-RK73H1JTTD1403F
U1: ISl91127IR; QFN50P400X400X90-21N; Mouser PN 968-ISL91127IRAZ-T

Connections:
EN: M1.3, U1.11 (EN)
GND: C1.2, C2.2, C4.2, C5.2, JP1.1 (A), M1.11 (GND), R2.2, U1.3 (PGND), U1.13 (SGND), U1.14 (SGND), U1.21 (EPAD)
MODE: M1.22, R4.2, U1.12 (MODE)
unnamed: L1.1, U1.4 (LX1), U1.5 (LX1)
unnamed: L1.2, U1.1 (LX2), U1.2 (LX2)
unnamed: C3.2, R1.2, R2.1, R5.1, U1.15 (FB)
VBAT: C1.1, C5.1, M1.1 (VCC), R4.1, U1.6 (PVIN), U1.7 (PVIN), U1.8 (PVIN), U1.9 (PVIN), U1.10 (VIN)
VCC_OUT: C2.1, C3.1, C4.1, M1.10, M1.13, M1.21, R1.1, U1.17 (VOUT), U1.18 (VOUT), U1.19 (VOUT), U1.20 (VOUT)
/5V_SEL: JP1.2 (B), M1.12, R5.2

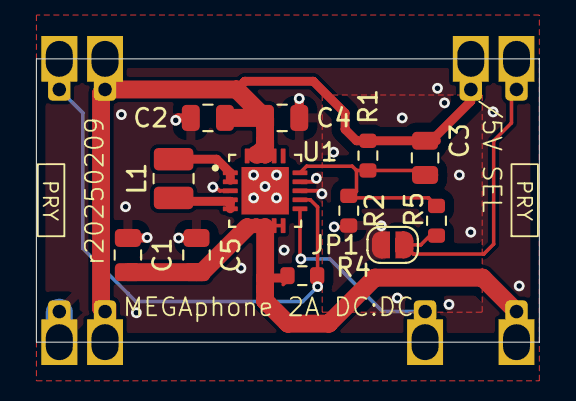
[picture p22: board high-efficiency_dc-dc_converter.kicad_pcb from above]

Board: 2 copper layers, 27.9 x 15.7 mm, 13 parts (1 on the bottom side), 9 nets.

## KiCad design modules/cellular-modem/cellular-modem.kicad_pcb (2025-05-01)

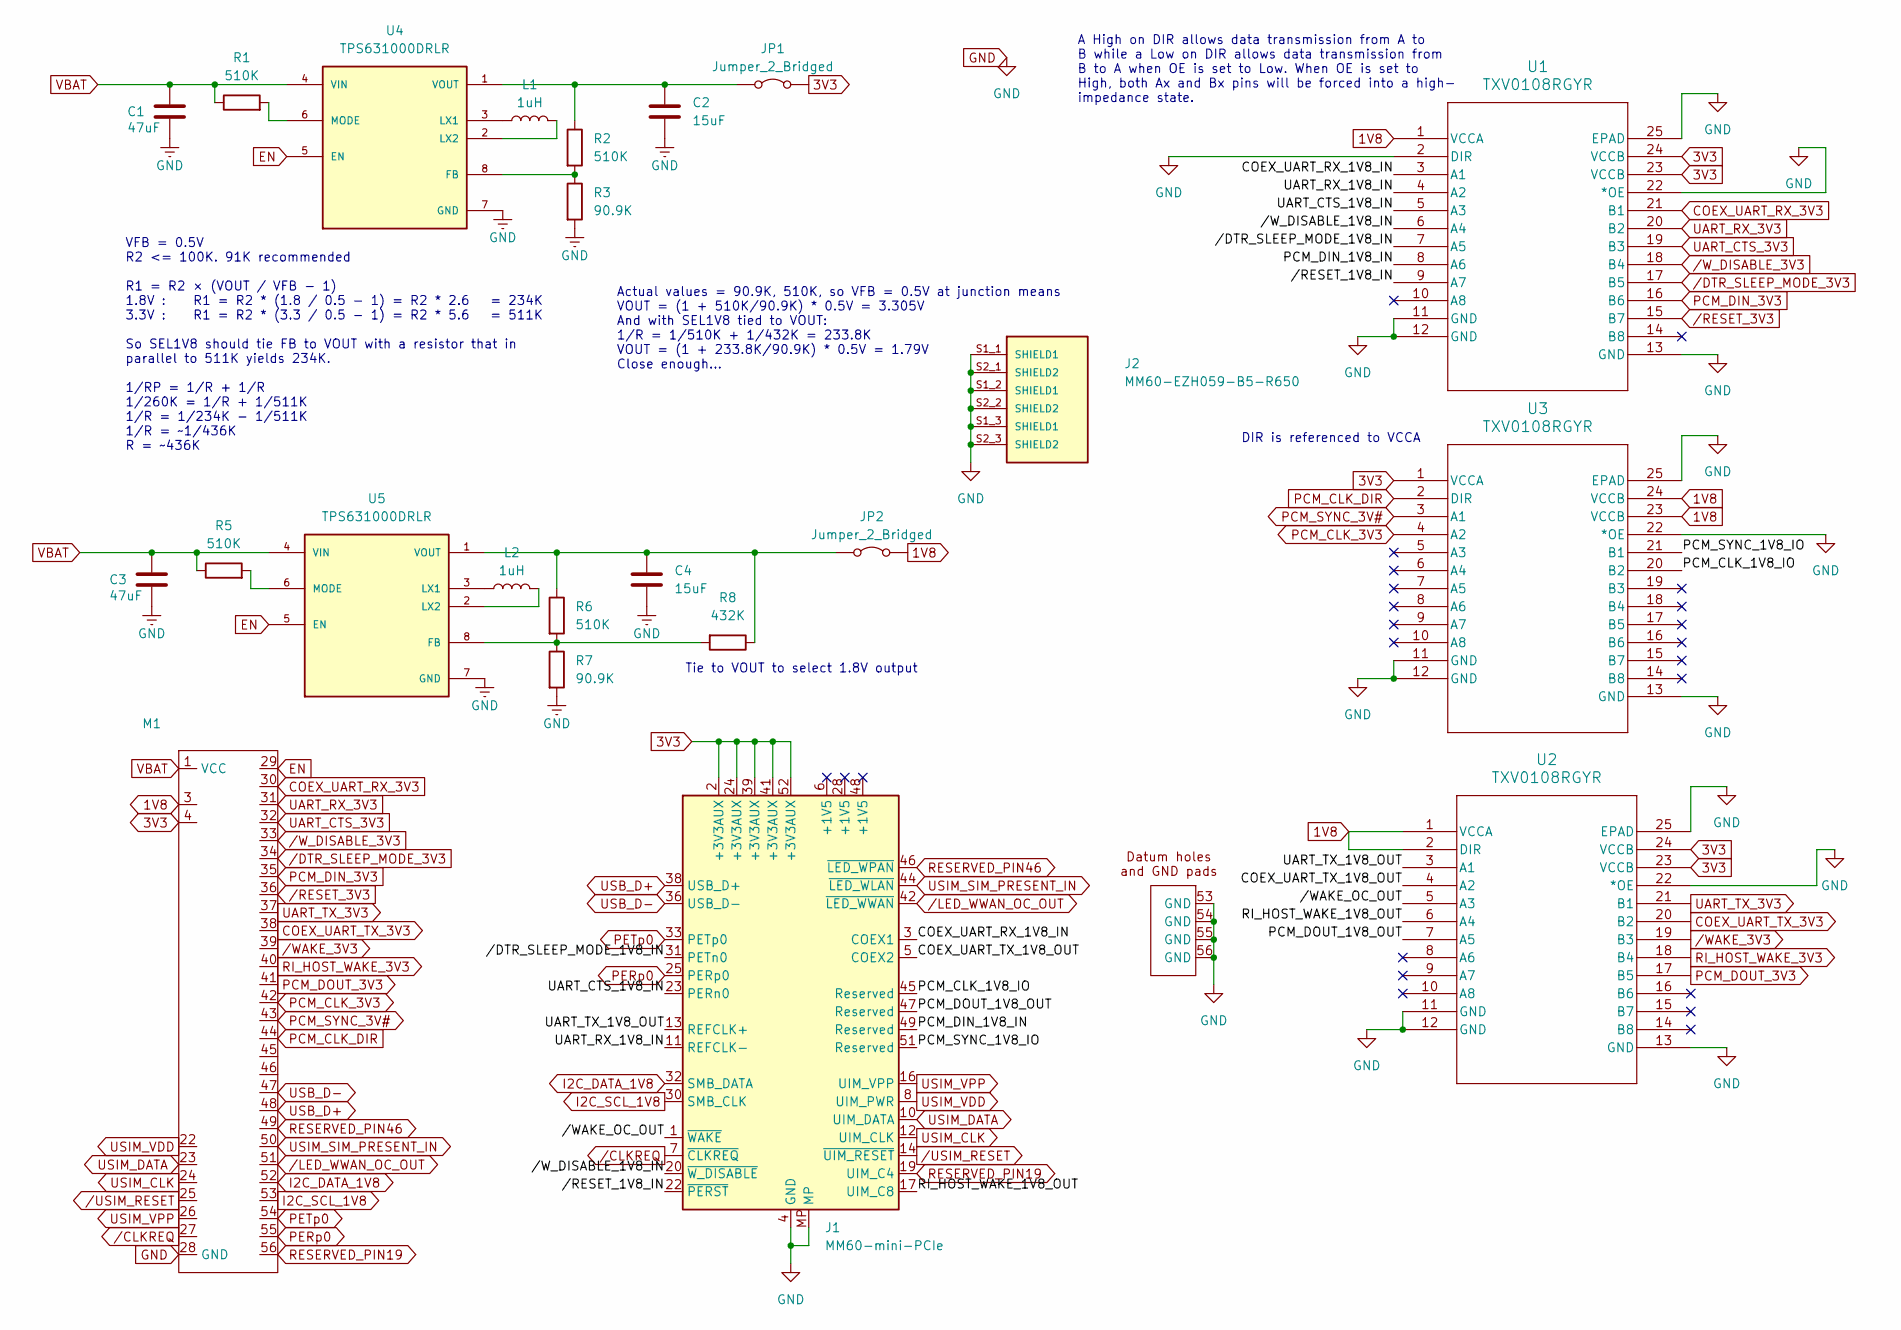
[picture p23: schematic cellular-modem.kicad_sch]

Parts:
C1: 47uF; C_0805_2012Metric; Mouser_PN GRM219R60J476ME44
C2, C4: 15uF; C_0805_2012Metric; Mfr. PN C2012X7S1A156M125AC; Mouser_PN 810-C2012X7S1A156M1C
C3: 47uF; C_0805_2012Metric; Mfr. PN GRM219R60J476ME44D; Mouser_PN GRM219R60J476ME44
J1: MM60-mini-PCIe; CONN_MM60-52B1-E1-R650_JAE; Mfr. PN MM60-52B1-G1-R850; Mouser_PN 656-MM6052B1G1R850
J2: MM60-EZH059-B5-R650; JAE_MM60-EZH059-B5-R650; PARTREV 3; Mouser_PN 656-MM60-EZH059-B5-R
JP1, JP2: Jumper_2_Bridged; SolderJumper-2_P1.3mm_Bridged2Bar_RoundedPad1.0x1.5mm
L1: 1uH; L_1008_2520Metric_Pad1.43x2.20mm_HandSolder; Mouser_PN 81-DFE252012P-1R0MP2
L2: 1uH; L_1008_2520Metric_Pad1.43x2.20mm_HandSolder; Mfr. PN DFE252012P-1R0M=P2; Mouser_PN 81-DFE252012P-1R0MP2
M1: MegaCastle2x28-Module-I42.8x66.3-MB00007FFFFFFFF-SPAREPAD
R1, R2, R5, R6: 510K; R_0805_2012Metric; Mouser_PN CR0805-JW-514ELF
R3, R7: 90.9K; R_0805_2012Metric; Mfr. PN RE0805FRE0790K9L; Mouser_PN 603-RE0805FRE0790K9L
R8: 432K; R_0805_2012Metric; Mfr. PN RC0805FR-07432KL; Mouser_PN 603-RC0805FR-07432KL
U1, U2, U3: TXV0108RGYR; VQFN24_RGY_TEX; Mfr. PN TXV0108RGYR; Mouser_PN 595-TXV0108RGYR
U4, U5: TPS631000DRLR; SOT50P160X60-8N; PARTREV B; Mouser_PN 595-TPS631000DRLR

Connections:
1V8: JP2.2 (B), M1.3, U1.1 (VCCA), U2.1 (VCCA), U2.2 (DIR), U3.23 (VCCB), U3.24 (VCCB)
3V3: J1.2 (+3V3AUX), J1.24 (+3V3AUX), J1.39 (+3V3AUX), J1.41 (+3V3AUX), J1.52 (+3V3AUX), JP1.2 (B), M1.4, U1.23 (VCCB), U1.24 (VCCB), U2.23 (VCCB), U2.24 (VCCB), U3.1 (VCCA)
/COEX_UART_RX_1V8_IN: J1.3 (COEX1), U1.3 (A1)
/COEX_UART_TX_1V8_OUT: J1.5 (COEX2), U2.4 (A2)
/PCM_CLK_1V8_IO: J1.45 (Reserved), U3.20 (B2)
/PCM_DIN_1V8_IN: J1.49 (Reserved), U1.8 (A6)
/PCM_DOUT_1V8_OUT: J1.47 (Reserved), U2.7 (A5)
/PCM_SYNC_1V8_IO: J1.51 (Reserved), U3.21 (B1)
/RI_HOST_WAKE_1V8_OUT: J1.17 (UIM_C8), U2.6 (A4)
/UART_CTS_1V8_IN: J1.23 (PERn0), U1.5 (A3)
/UART_RX_1V8_IN: J1.11 (REFCLK-), U1.4 (A2)
/UART_TX_1V8_OUT: J1.13 (REFCLK+), U2.3 (A1)
//DTR_SLEEP_MODE_1V8_IN: J1.31 (PETn0), U1.7 (A5)
//RESET_1V8_IN: J1.22 (~PERST), U1.9 (A7)
//WAKE_OC_OUT: J1.1 (~WAKE), U2.5 (A3)
//W_DISABLE_1V8_IN: J1.20 (~W_DISABLE), U1.6 (A4)
COEX_UART_RX_3V3: M1.30, U1.21 (B1)
COEX_UART_TX_3V3: M1.38, U2.20 (B2)
EN: M1.29, U4.5 (EN), U5.5 (EN)
GND: C1.1, C2.2, C3.1, C4.2, J1.4 (GND), J1.9 (GND), J1.15 (GND), J1.18 (GND), J1.21 (GND), J1.26 (GND), J1.27 (GND), J1.29 (GND), J1.34 (GND), J1.35 (GND), J1.37 (GND), J1.40 (GND), J1.43 (GND), J1.50 (GND), J1.53 (GND), J1.54 (GND), J1.55 (GND), J1.56 (GND), J1.MP, J2.S1_1 (SHIELD1), J2.S1_2 (SHIELD1), J2.S1_3 (SHIELD1), J2.S2_1 (SHIELD2), J2.S2_2 (SHIELD2), J2.S2_3 (SHIELD2), M1.28 (GND), R3.2, R7.2, U1.2 (DIR), U1.11 (GND), U1.12 (GND), U1.13 (GND), U1.22 (*OE), U1.25 (EPAD), U2.11 (GND), U2.12 (GND), U2.13 (GND), U2.22 (*OE), U2.25 (EPAD), U3.11 (GND), U3.12 (GND), U3.13 (GND), U3.22 (*OE), U3.25 (EPAD), U4.7 (GND), U5.7 (GND)
I2C_DATA_1V8: J1.32 (SMB_DATA), M1.52
I2C_SCL_1V8: J1.30 (SMB_CLK), M1.53
unnamed: C2.1, JP1.1 (A), R2.1, U4.1 (VOUT)
unnamed: C4.1, JP2.1 (A), R6.1, R8.1, U5.1 (VOUT)
unnamed: R2.2, R3.1, U4.8 (FB)
unnamed: L1.1, U4.3 (LX1)
unnamed: L1.2, U4.2 (LX2)
unnamed: R1.2, U4.6 (MODE)
unnamed: R6.2, R7.1, R8.2, U5.8 (FB)
unnamed: L2.1, U5.3 (LX1)
unnamed: L2.2, U5.2 (LX2)
unnamed: R5.2, U5.6 (MODE)
PCM_CLK_3V3: M1.42, U3.4 (A2)
PCM_CLK_DIR: M1.44, U3.2 (DIR)
PCM_DIN_3V3: M1.35, U1.16 (B6)
PCM_DOUT_3V3: M1.41, U2.17 (B5)
PCM_SYNC_3V#: M1.43, U3.3 (A1)
PERp0: J1.25 (PERp0), M1.55
PETp0: J1.33 (PETp0), M1.54
RESERVED_PIN19: J1.19 (UIM_C4), M1.56
RESERVED_PIN46: J1.46 (~LED_WPAN), M1.49
RI_HOST_WAKE_3V3: M1.40, U2.18 (B4)
UART_CTS_3V3: M1.32, U1.19 (B3)
UART_RX_3V3: M1.31, U1.20 (B2)
UART_TX_3V3: M1.37, U2.21 (B1)
USB_D+: J1.38 (USB_D+), M1.48
USB_D-: J1.36 (USB_D-), M1.47
USIM_CLK: J1.12 (UIM_CLK), M1.24
USIM_DATA: J1.10 (UIM_DATA), M1.23
USIM_SIM_PRESENT_IN: J1.44 (~LED_WLAN), M1.50
USIM_VDD: J1.8 (UIM_PWR), M1.22
USIM_VPP: J1.16 (UIM_VPP), M1.26
VBAT: C1.2, C3.2, M1.1 (VCC), R1.1, R5.1, U4.4 (VIN), U5.4 (VIN)
/CLKREQ: J1.7 (~CLKREQ), M1.27
/DTR_SLEEP_MODE_3V3: M1.34, U1.17 (B5)
/LED_WWAN_OC_OUT: J1.42 (~LED_WWAN), M1.51
/RESET_3V3: M1.36, U1.15 (B7)
/USIM_RESET: J1.14 (~UIM_RESET), M1.25
/WAKE_3V3: M1.39, U2.19 (B3)
/W_DISABLE_3V3: M1.33, U1.18 (B4)

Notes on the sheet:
Tie to VOUT to select 1.8V output
Actual values = 90.9K, 510K, so VFB = 0.5V at junction means VOUT = (1 + 510K/90.9K) * 0.5V = 3.305V And with SEL1V8 tied to VOUT: 1/R = 1/510K + 1/432K = 233.8K VOUT = (1 + 233.8K/90.9K) * 0.5V = 1.79V Close enough...
VFB = 0.5V R2 <= 100K. 91K recommended R1 = R2 × (VOUT / VFB - 1) 1.8V : R1 = R2 * (1.8 / 0.5 - 1) = R2 * 2.6 = 234K 3.3V : R1 = R2 * (3.3 / 0.5 - 1) = R2 * 5.6 = 511K So SEL1V8 should tie FB to VOUT with a resistor that in parallel to 511K yields 234K. 1/RP = 1/R + 1/R 1/260K = 1/R + 1/511K 1/R = 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
DIR is referenced to VCCA
A High on DIR allows data transmission from A to B while a Low on DIR allows data transmission from B to A when OE is set to Low. When OE is set to High, both Ax and Bx pins will be forced into a high- impedance state.

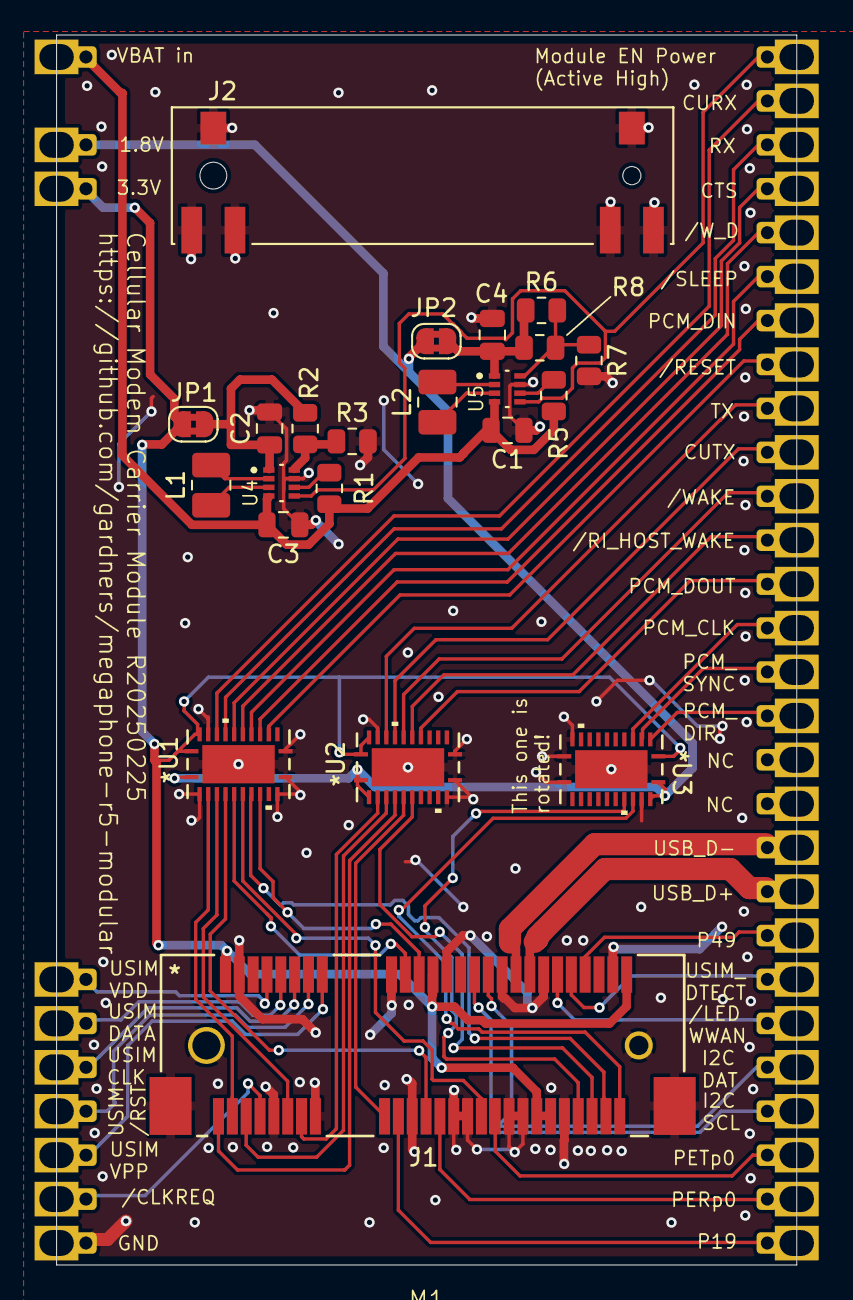
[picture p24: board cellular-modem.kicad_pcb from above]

Board: 4 copper layers, 42.8 x 71.1 mm, 23 parts (0 on the bottom side), 60 nets.

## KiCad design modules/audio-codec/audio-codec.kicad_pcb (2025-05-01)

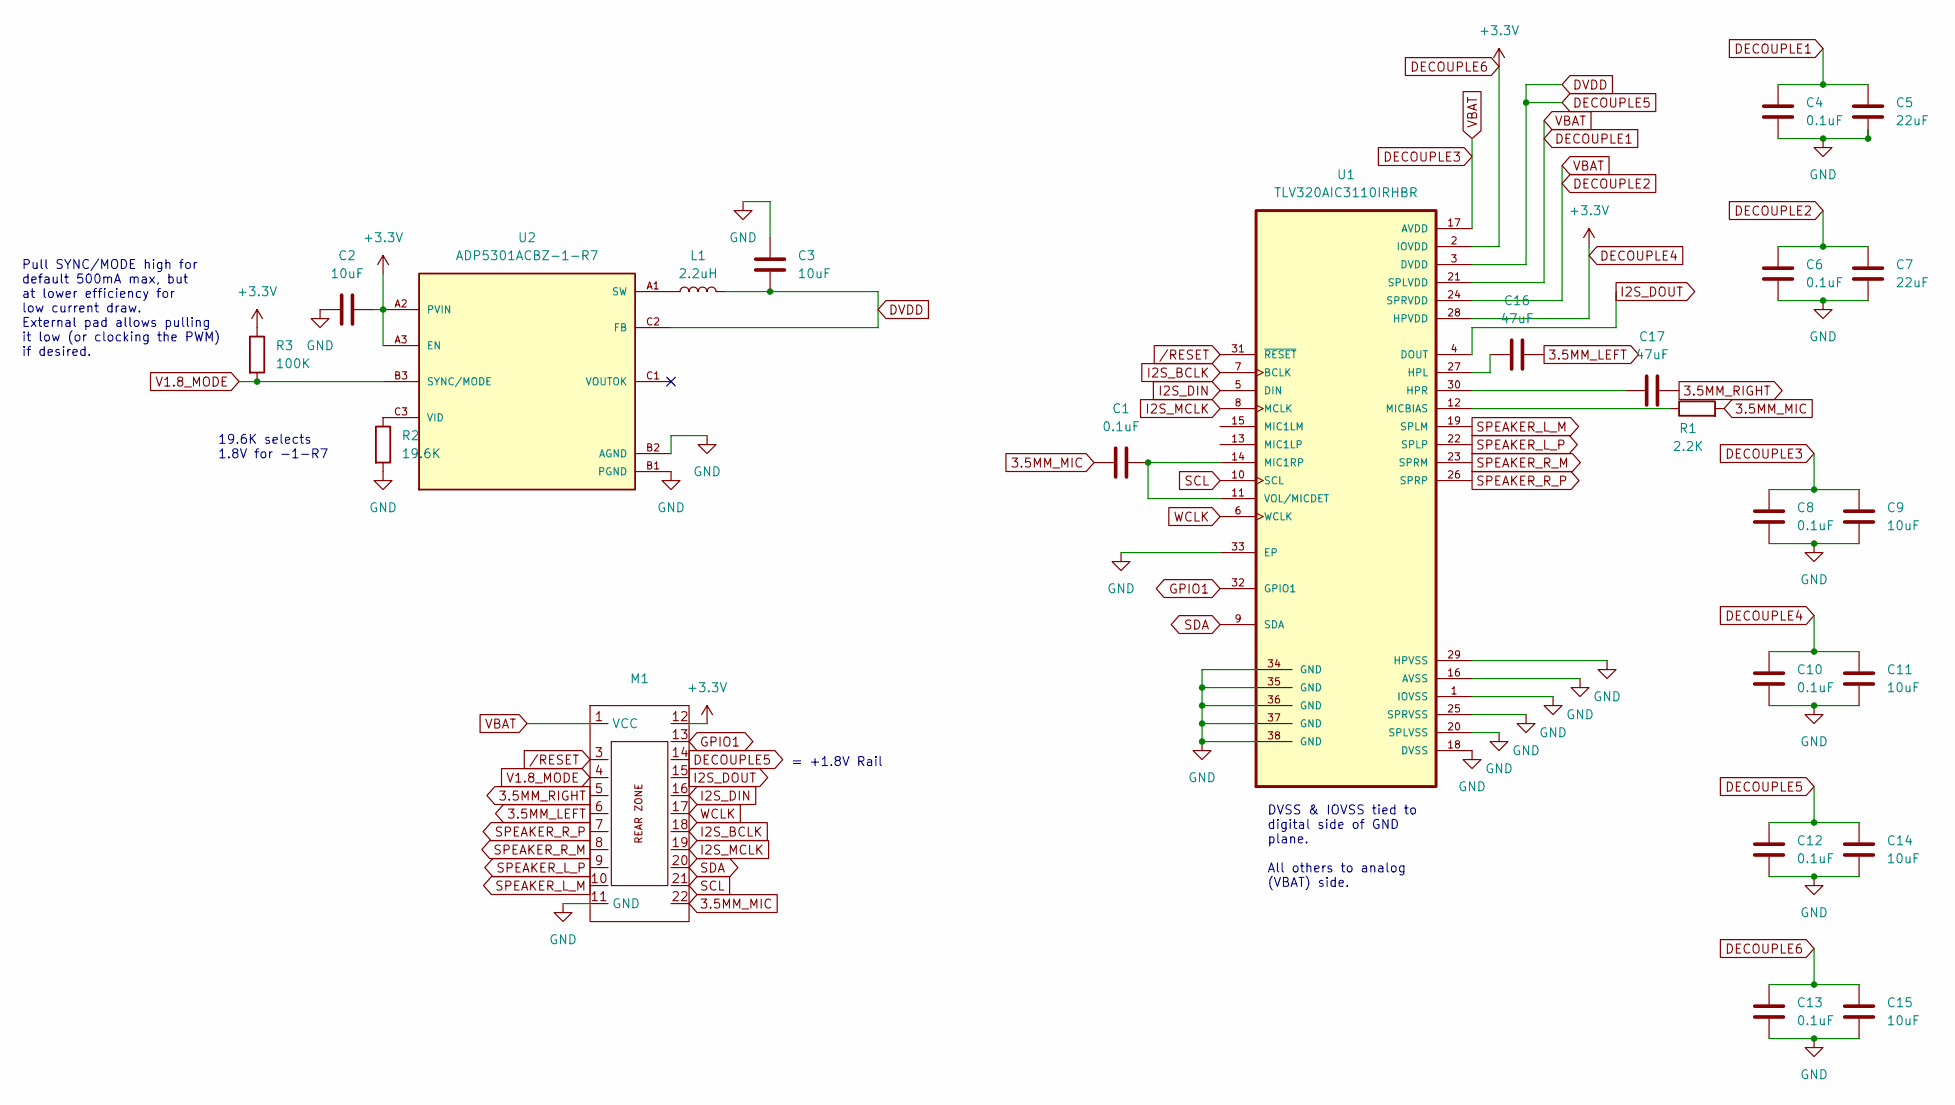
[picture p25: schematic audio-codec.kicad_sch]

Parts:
C1, C4, C6, C8, C10, C12, C13: 0.1uF; C_0603_1608Metric; Mfr. PN C0603C104M4RAC; Mouser PN 80-C0603C104M4RAC
C2, C3, C9, C11, C14, C15: 10uF; C_0603_1608Metric; Mfr. PN C0603C106M9PAC7411; Mouser PN 80-C0603C106M9P7411
C5, C7: 22uF; C_0603_1608Metric; Mfr. PN CC0603MRX5R5BB226; Mouser PN 603-CC603MRX5R5BB226
C16, C17: 47uF; C_0603_1608Metric; Mfr. PN GRM188R60E476ME15J; Mouser PN 81-GRM188R60E476ME5J
L1: 2.2uH; L_0805_2012Metric; Mouser PN 810-MLP2016V2R2MT0S1
M1: MegaCastle2x11-Module-I22.0x23.1-MBFFFFC-SPAREPAD
R1: 2.2K; R_0603_1608Metric; Mfr. PN RT0603DRE072K2L; Mouser PN 603-RT0603DRE072K2L
R2: 19.6K; R_0603_1608Metric; Mouser PN 603-RT0603BRD0719K6L
R3: 100K; R_0603_1608Metric; Mouser PN 603-RC0603FR-07100KL
U1: TLV320AIC3110IRHBR; IC_ADS125H01IRHBT; Mouser PN 595-V320AIC3110IRHBR
U2: ADP5301ACBZ-1-R7; BGA9C50P3X3_187X165X66N; Mouser PN 584-ADP5301ACBZ-1-R7

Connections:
3.5MM_LEFT: C16.2, M1.6
3.5MM_MIC: C1.2, M1.22, R1.2
3.5MM_RIGHT: C17.2, M1.5
DECOUPLE1: C4.1, C5.1, C6.1, C7.1, C8.1, C9.1, M1.1 (VCC), U1.17 (AVDD), U1.21 (SPLVDD), U1.24 (SPRVDD)
DECOUPLE4: C2.2, C10.1, C11.1, C13.1, C15.1, M1.12, R3.1, U1.2 (IOVDD), U1.28 (HPVDD), U2.A2 (PVIN), U2.A3 (EN)
DECOUPLE5: C3.1, C12.1, C14.1, L1.2, M1.14, U1.3 (DVDD), U2.C2 (FB)
GND: C2.1, C3.2, C4.2, C5.2, C6.2, C7.2, C8.2, C9.2, C10.2, C11.2, C12.2, C13.2, C14.2, C15.2, M1.11 (GND), R2.2, U1.1 (IOVSS), U1.16 (AVSS), U1.18 (DVSS), U1.20 (SPLVSS), U1.25 (SPRVSS), U1.29 (HPVSS), U1.33 (EP), U1.34 (GND), U1.35 (GND), U1.36 (GND), U1.37 (GND), U1.38 (GND), U2.B1 (PGND), U2.B2 (AGND)
GPIO1: M1.13, U1.32 (GPIO1)
I2S_BCLK: M1.18, U1.7 (BCLK)
I2S_DIN: M1.16, U1.5 (DIN)
I2S_DOUT: M1.15, U1.4 (DOUT)
I2S_MCLK: M1.19, U1.8 (MCLK)
unnamed: C16.1, U1.27 (HPL)
unnamed: C17.1, U1.30 (HPR)
unnamed: C1.1, U1.11 (VOL/MICDET), U1.14 (MIC1RP)
unnamed: R1.1, U1.12 (MICBIAS)
unnamed: L1.1, U2.A1 (SW)
unnamed: R2.1, U2.C3 (VID)
SCL: M1.21, U1.10 (SCL)
SDA: M1.20, U1.9 (SDA)
SPEAKER_L_M: M1.10, U1.19 (SPLM)
SPEAKER_L_P: M1.9, U1.22 (SPLP)
SPEAKER_R_M: M1.8, U1.23 (SPRM)
SPEAKER_R_P: M1.7, U1.26 (SPRP)
V1.8_MODE: M1.4, R3.2, U2.B3 (SYNC/MODE)
WCLK: M1.17, U1.6 (WCLK)
/RESET: M1.3, U1.31 (~RESET)

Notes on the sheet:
Pull SYNC/MODE high for default 500mA max, but at lower efficiency for low current draw. External pad allows pulling it low (or clocking the PWM) if desired.
19.6K selects 1.8V for -1-R7
= +1.8V Rail
DVSS & IOVSS tied to digital side of GND plane. All others to analog (VBAT) side.

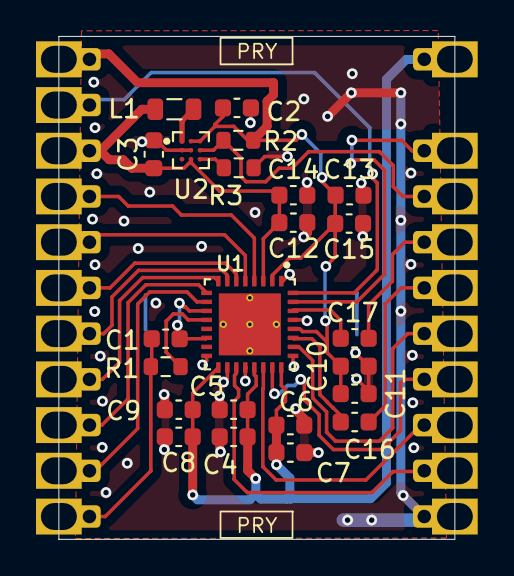
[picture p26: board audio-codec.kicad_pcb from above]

Board: 2 copper layers, 22.0 x 27.9 mm, 24 parts (1 on the bottom side), 27 nets.

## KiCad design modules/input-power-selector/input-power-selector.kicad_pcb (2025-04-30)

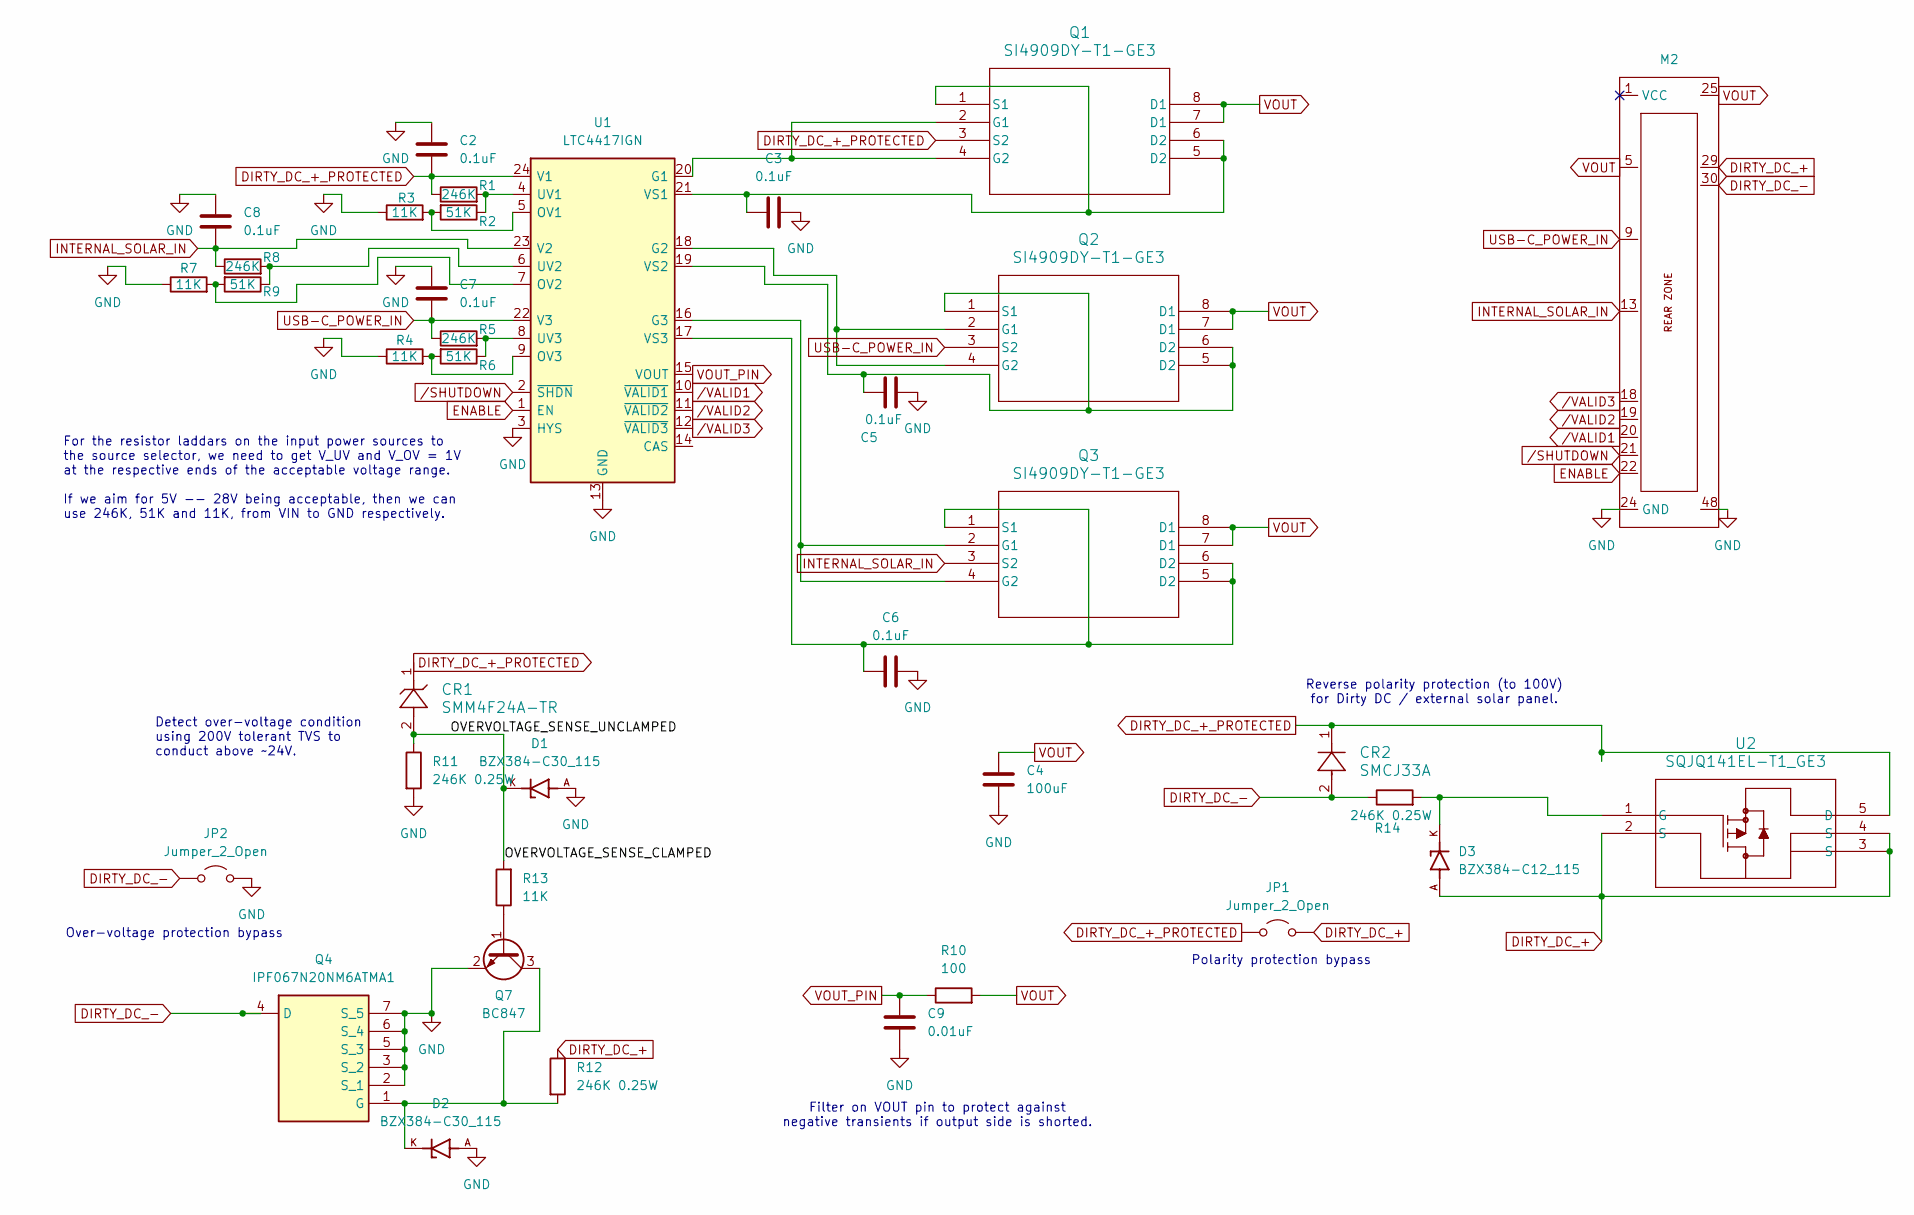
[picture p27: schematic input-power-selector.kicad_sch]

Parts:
C2, C3, C5, C6, C7, C8: 0.1uF; C_0805_2012Metric; Manufacturer_Part_Number 0805DC104MAT2A; Mouser Part Number 581-0805DC104MAT2A
C4: 100uF; C_0805_2012Metric
C9: 0.01uF; C_0805_2012Metric
CR1: SMM4F24A-TR; Manufacturer_Part_Number SMM4F24A-TR; Mouser Part Number 511-SMM4F24A-TR
CR2: SMCJ33A; Manufacturer_Part_Number 652-SMCJ33A; Mouser Part Number SMCJ33A
D1, D2: BZX384-C30_115; DIO_BZX384-C30_115; Manufacturer_Part_Number BZX384-C30,115; Mouser Part Number 771-BZX384-C30115
D3: BZX384-C12_115; DIO_BZX384-C30_115; Manufacturer_Part_Number BZX384-C12,115; Mouser Part Number 771-BZX384-C12115
JP1, JP2: Jumper_2_Open; SolderJumper-2_P1.3mm_Open_RoundedPad1.0x1.5mm
M2: MegaCastle2x24-Module-I47.0x56.2-M88887D8C0001-SPAREPAD
Q1, Q2, Q3: SI4909DY-T1-GE3; Manufacturer_Part_Number SI4909DY-T1-GE3; Mouser Part Number 78-SI4909DY-T1-GE3
Q4: IPF067N20NM6ATMA1; Mouser Part Number 726-IPF067N20NM6ATMA
Q7: BC847; SOT-23; Manufacturer_Part_Number 637-BC847B; Mouser Part Number BC847B
R1, R5, R8: 246K; R_0805_2012Metric
R2, R6, R9: 51K; R_0805_2012Metric; Manufacturer_Part_Number RV0805FR-0751KL; Mouser Part Number 603-RV0805FR-0751KL
R3, R4, R7, R13: 11K; R_0805_2012Metric; Manufacturer_Part_Number RT0805DRE0711KL; Mouser Part Number 603-RT0805DRE0711KL
R10: 100; R_0805_2012Metric; Manufacturer_Part_Number PCF0805R-100RBI; Mouser Part Number 756-PCF0805R100RBI
R11, R12, R14: 246K 0.25W; R_0805_2012Metric; Manufacturer_Part_Number PTN0805E2463BST1; Mouser Part Number 71-PTN0805E2463BST1
U1: LTC4417IGN; SSOP-24_3.9x8.7mm_P0.635mm; Manufacturer_Part_Number LTC4417IGN#PBF; Mouser Part Number 584-LTC4417IGN#PBF
U2: SQJQ141EL-T1_GE3; SOT95P280X120-6N; Manufacturer_Part_Number SQJQ141EL-T1_GE3; Mouser Part Number 78-SQJQ141EL-T1_GE3

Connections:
/OVERVOLTAGE_SENSE_CLAMPED: CR1.2, D1.K, R11.1, R13.2
DIRTY_DC_+: D3.A, JP1.2 (B), M2.29, R12.1, U2.2 (S), U2.3 (S), U2.4 (S)
DIRTY_DC_+_PROTECTED: C2.2, CR1.1, CR2.1, JP1.1 (A), Q1.3 (S2), R1.1, U1.24 (V1), U2.5 (D)
DIRTY_DC_-: CR2.2, JP2.1 (A), M2.30, Q4.4 (D), R14.1
ENABLE: M2.22, U1.1 (EN)
GND: C2.1, C3.2, C4.2, C5.2, C6.2, C7.1, C8.1, C9.2, D1.A, D2.A, JP2.2 (B), M2.24 (GND), M2.48, Q4.2 (S_1), Q4.3 (S_2), Q4.5 (S_3), Q4.6 (S_4), Q4.7 (S_5), Q7.2 (E), R3.1, R4.1, R7.1, R11.2, U1.3 (HYS), U1.13 (GND)
INTERNAL_SOLAR_IN: C8.2, M2.13, Q3.3 (S2), R8.1, U1.23 (V2)
unnamed: Q1.2 (G1), Q1.4 (G2), U1.20 (G1)
unnamed: C3.1, Q1.1 (S1), Q1.5 (D2), Q1.6 (D2), U1.21 (VS1)
unnamed: Q2.2 (G1), Q2.4 (G2), U1.18 (G2)
unnamed: C5.1, Q2.1 (S1), Q2.5 (D2), Q2.6 (D2), U1.19 (VS2)
unnamed: Q3.2 (G1), Q3.4 (G2), U1.16 (G3)
unnamed: C6.1, Q3.1 (S1), Q3.5 (D2), Q3.6 (D2), U1.17 (VS3)
unnamed: D2.K, Q4.1 (G), Q7.3 (C), R12.2
unnamed: Q7.1 (B), R13.1
unnamed: R2.2, R3.2, U1.5 (OV1)
unnamed: R7.2, R9.2, U1.7 (OV2)
unnamed: R4.2, R6.2, U1.9 (OV3)
unnamed: R1.2, R2.1, U1.4 (UV1)
unnamed: R8.2, R9.1, U1.6 (UV2)
unnamed: R5.2, R6.1, U1.8 (UV3)
unnamed: D3.K, R14.2, U2.1 (G)
USB-C_POWER_IN: C7.2, M2.9, Q2.3 (S2), R5.1, U1.22 (V3)
VOUT: C4.1, M2.5, M2.25, Q1.7 (D1), Q1.8 (D1), Q2.7 (D1), Q2.8 (D1), Q3.7 (D1), Q3.8 (D1), R10.2
VOUT_PIN: C9.1, R10.1, U1.15 (VOUT)
/SHUTDOWN: M2.21, U1.2 (~SHDN)
/VALID1: M2.20, U1.10 (~VALID1)
/VALID2: M2.19, U1.11 (~VALID2)
/VALID3: M2.18, U1.12 (~VALID3)

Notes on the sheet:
For the resistor laddars on the input power sources to the source selector, we need to get V_UV and V_OV = 1V at the respective ends of the acceptable voltage range. If we aim for 5V -- 28V being acceptable, then we can use 246K, 51K and 11K, from VIN to GND respectively.
Filter on VOUT pin to protect against negative transients if output side is shorted.
Reverse polarity protection (to 100V) for Dirty DC / external solar panel.
Over-voltage protection bypass
Detect over-voltage condition using 200V tolerant TVS to conduct above ~24V.
Polarity protection bypass

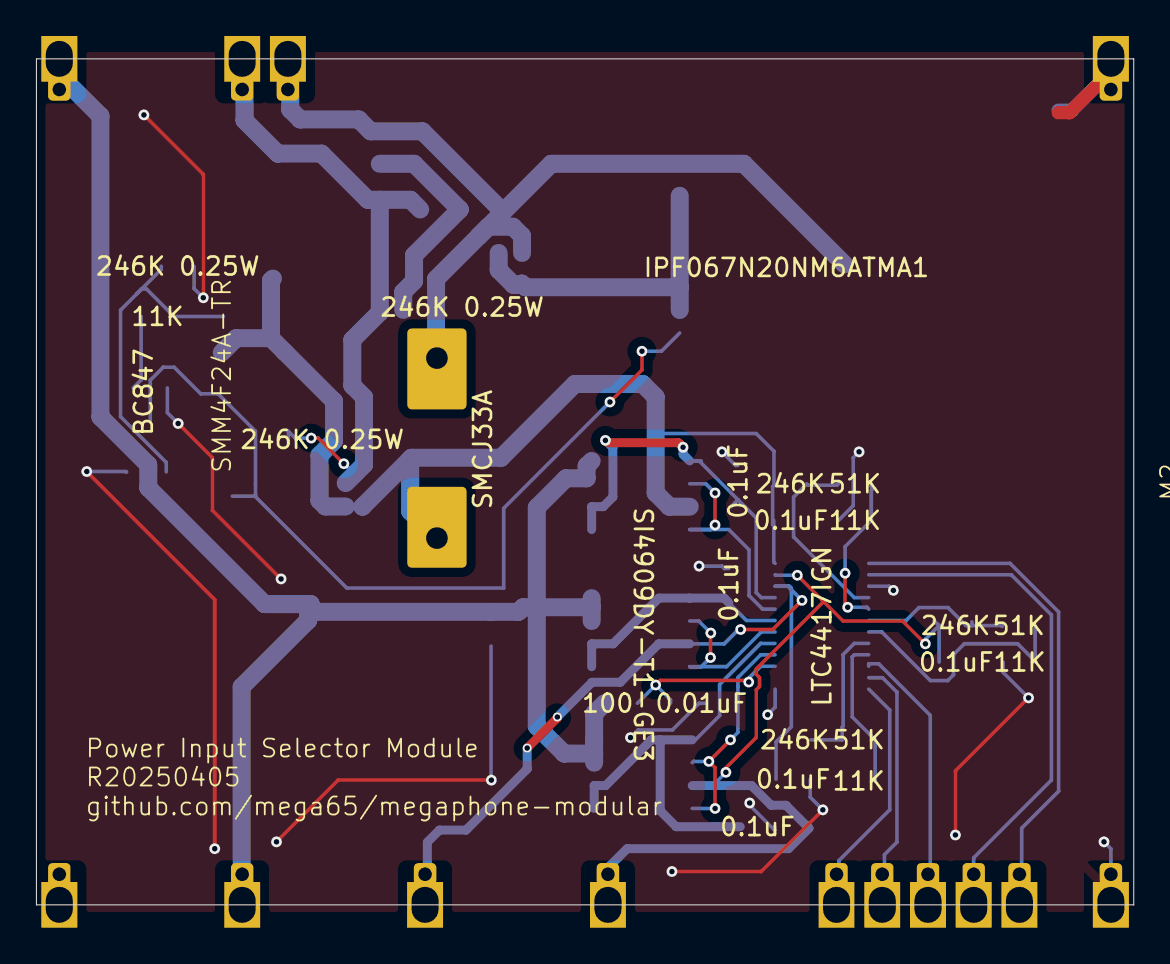
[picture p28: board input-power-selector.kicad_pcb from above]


Board: 2 copper layers, 61.0 x 47.0 mm, 37 parts (36 on the bottom side), 29 nets.

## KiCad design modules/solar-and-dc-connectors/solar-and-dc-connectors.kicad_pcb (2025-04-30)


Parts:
J1: S2B-PH-K-SLFSN; CONN_S2B-PH-K-S_JST; Mouser PN 306-S2BPHKSLFSNPP
J2: 54-00127; TENSILITY_54-00127; PARTREV A
M1: MegaCastle2x12-Module-I20.0x25.7-M80181F-SPAREPAD

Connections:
DIRTY_DC_+: J2.A, M1.13
DIRTY_DC_-: J2.B, M1.20
DIRTY_DC_-_SENSE: J2.C, M1.21
GND: J1.2, M1.12 (GND)
INTERNAL_SOLAR_+: J1.1, M1.24


Board: 2 copper layers, 20.0 x 30.5 mm, 3 parts (0 on the bottom side), 5 nets.

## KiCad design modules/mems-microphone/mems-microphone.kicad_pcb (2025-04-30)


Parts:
C1: 100nF; C_1206_3216Metric; Mouser PN 581-12066D104KAT4A
M1: MegaCastle2x5-Module-I10.0x7.9-M9C4-SPAREPAD
MK1: IM69D130; Knowles_LGA-5_3.5x2.65mm; Mouser PN 726-IM69D130V01XTSA1
R1: 100; R_0603_1608Metric; Mfr. PN AC0603JR-07100RL; Mouser PN 603-AC0603JR-07100RL
R2: 100; R_0603_1608Metric; Mouser PN 603-AC0603JR-07100RL
R3: 100K; R_0603_1608Metric; Mouser PN 603-AC0603JR-07100KL

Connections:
CLOCK: M1.6, R2.2
DATA: M1.10, R1.1
GND: C1.2, M1.5 (GND), MK1.3 (GND)
LR_SELECT: M1.4, MK1.2 (SEL), R3.1
unnamed: MK1.4 (CLOCK), R2.1
unnamed: MK1.1 (DATA), R1.2
VCC: C1.1, M1.1 (VCC), MK1.5 (VDD), R3.2


Board: 2 copper layers, 10.0 x 12.7 mm, 6 parts (1 on the bottom side), 7 nets.

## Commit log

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2024-10-03 begin working on simple test carrier board
    [scratch-project.kicad_pcb, scratch-project.kicad_sch]
2024-10-03 fix pad sizes and schematic errors
    [scratch-project.kicad_pcb, scratch-project.kicad_sch]
2024-10-03 fix 2x10 wide footprint. add modules to scratch board
    [scratch-project.kicad_pcb, scratch-project.kicad_sch]
2024-10-03 finish adding dummy modules to scratch board
    [scratch-project.kicad_pcb, scratch-project.kicad_sch]
2024-10-04 apply pcbway advice for panels
    [scratch-project.kicad_pcb, scratch-project.kicad_sch]
2025-02-06 add collated requirements from blog post
    [requirements.csv]
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2025-02-07 fix Trenz FPGA board part number
    [requirements.csv]
2025-02-08 begin work on DC:DC converter module schematic
    [high-efficiency_dc-dc_converter.kicad_pcb, high-efficiency_dc-dc_converter.kicad_sch]
2025-02-08 assign footprints for passives for DC:DC converter module
    [high-efficiency_dc-dc_converter.kicad_sch]
2025-02-08 add QFN20 footprint for DC:DC converter IC
    [high-efficiency_dc-dc_converter.kicad_sch]
2025-02-08 add footprints to PCB
    [high-efficiency_dc-dc_converter.kicad_pcb]
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2025-02-08 update schematic, slightly compact PCB layout
    [high-efficiency_dc-dc_converter.kicad_pcb, high-efficiency_dc-dc_converter.kicad_sch]
2025-02-08 add 2x11 module symbol and footprint and use for DC:DC module
    [high-efficiency_dc-dc_converter.kicad_pcb, high-efficiency_dc-dc_converter.kicad_sch]
2025-02-08 rearrange pins etc to keep to 2-layer for DC:DC module
    [high-efficiency_dc-dc_converter.kicad_pcb, high-efficiency_dc-dc_converter.kicad_sch]
2025-02-08 add silkscreen hints etc to 2A DC:DC Module
    [high-efficiency_dc-dc_converter.kicad_pcb]
2025-02-08 update board date and rev fields
    [high-efficiency_dc-dc_converter.kicad_sch]
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2025-02-09 note changes to requirements
    [requirements.csv]
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2025-02-10 add schematic for MEMS module using 2x5 - 4 pins
    [mems-microphone.kicad_pcb, mems-microphone.kicad_sch]
2025-02-10 begin work on pcb layout for MEMS module
    [mems-microphone.kicad_pcb, mems-microphone.kicad_sch]
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2025-02-10 add missing files for module footprints
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2025-02-11 add footprints for passives for MEMS mic module
    [mems-microphone.kicad_pcb, mems-microphone.kicad_sch]
2025-02-11 use 0603 resistors to make it all fit
    [mems-microphone.kicad_pcb]
2025-02-11 begin work on audio codec module
    [TLV320AIC3110IRHBR.step, audio-codec.kicad_pcb, audio-codec.kicad_sch]
2025-02-11 save changes to mems microphone module
    [mems-microphone.kicad_pcb]
2025-02-11 update and correct 2x5-M9C4 module footprint
2025-02-11 add footprint for audio codec IC
    [audio-codec.kicad_pcb, audio-codec.kicad_sch]
2025-02-11 add ADP5301 vreg and work on schematic
    [ADP5301ACBZ-1-R7.step, audio-codec.kicad_sch]
2025-02-11 more work on audio codec module
    [audio-codec.kicad_sch]
2025-02-11 add 1.8V test point
    [audio-codec.kicad_sch]
2025-02-11 add remaining passives for audio codec module schematic
    [audio-codec.kicad_sch]
2025-02-12 update 2x11 module footprint. Work on PCB layout of audio codec module
    [audio-codec.kicad_pcb, audio-codec.kicad_sch]
2025-02-12 more work on audio codec PCB layout
    [audio-codec.kicad_pcb, audio-codec.kicad_sch]
2025-02-12 finish placing and routing audio codec module
    [audio-codec.kicad_pcb, audio-codec.kicad_sch]
2025-02-12 add gnd pads to codec thermal pad, tidy passives and label on rear
    [audio-codec.kicad_pcb, audio-codec.kicad_sch]
2025-02-13 add footprint and symbol for 3.5mm audio jack
    [SJ-43514-SMT-TR.step]
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2025-02-13 fix layers for some measurements in footprints
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2025-02-14 fix position of GND and VCC bridge silkscreen
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2025-02-14 position PRY and component cut out zones correctly
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2025-02-14 add front courtyard and fix edge type footprints
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2025-02-19 correct footprint for procedurally generated symbols
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2025-02-19 update audio codec module footprint and generate gerbers
    [audio-codec.kicad_pcb, audio-codec.kicad_sch]
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2025-02-21 update scratch project to have current module footprints
    [scratch-project.kicad_pcb, scratch-project.kicad_sch]
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2025-02-23 layout USB lines to alegedly have correct impedance
    [cellular-modem.kicad_pcb, cellular-modem.kicad_sch]
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2025-02-23 add 3.3V and 1.8V DC:DC to cellular modem module
    [cellular-modem.kicad_pcb, cellular-modem.kicad_sch]
2025-02-23 add footprints and models for mini PCIe connectors
    [MM60-52B1-E1-R2 JAE Connector Division Proprietary.step, MM60-EZH059-B5-R2 JAE Connector Division Proprietary.step]
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2025-02-24 switch to and place MM60 symbols and footprints
    [cellular-modem.kicad_pcb, cellular-modem.kicad_sch]
2025-02-24 add missing shield pads to MM60 retainer
    [cellular-modem.kicad_pcb, cellular-modem.kicad_sch]
2025-02-24 add 3D models for missing components
    [cellular-modem.kicad_pcb]
2025-02-24 add jumpers for isolating 1.8V and 3.3V regulators
    [cellular-modem.kicad_pcb, cellular-modem.kicad_sch]
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2025-02-25 begin work on SIM / SD card module
    [104168-1616.stp, cellular-modem.kicad_pcb, sim-and-sd-card.kicad_pcb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]
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2025-02-28 fix requirement numbering transposition
    [requirements.csv]
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2025-03-05 finish SD and SIM card holder footprint and symbol
    [sim-and-sd-card.kicad_pcb, sim-and-sd-card.kicad_sch]
2025-03-05 reverse text direction for part labels on DC:DC
    [high-efficiency_dc-dc_converter.kicad_pcb]
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2025-03-05 finish usb-c power in module and generate gerbers
    [usb-c-power-in.kicad_pcb, usb-c-power-in.kicad_sch]
2025-03-05 add footprints for MOSFETs for input power selecter
    [usb-c-power-in.kicad_pcb, usb-c-power-in.kicad_sch]
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2025-03-05 add symbols and footprints for input power selector components
    [input-power-selector.kicad_sch]
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2025-03-05 finish laying out schematic for power selector input protection
    [input-power-selector.kicad_sch]
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2025-03-05 add footprints for SMCJ28A. work on reverse polarity protection
    [input-power-selector.kicad_sch]
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2025-03-05 more layout fixing on power selector
    [input-power-selector.kicad_pcb, input-power-selector.kicad_sch]
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2025-03-05 add missing 3D model
    [SOIC_09DY-T1-GE3_VIS.step]
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2025-03-05 fix remaining important DRC violations
    [input-power-selector.kicad_pcb]
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2025-03-05 begin working on solar and DC power input module
    [solar-and-dc-connectors.kicad_pcb, solar-and-dc-connectors.kicad_sch]
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2025-03-05 add missing footprints and symbols
    [input-power-selector.kicad_pcb, input-power-selector.kicad_sch, solar-and-dc-connectors.kicad_pcb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]
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2025-03-12 get oauth working, but flow is still broken
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2025-03-22 fix bm83 uart rx framing
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2025-04-25 fix sparepad footprint problems
2025-04-25 fix typo in footprint-gen.c
2025-04-25 fix pin numbers and shape for right half
2025-04-28 Updating cellular modem - adding KiCad git ignore
    [cellular-modem.kicad_pcb, cellular-modem.kicad_sch]
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2025-07-28 fix end-of-file chain
2025-07-31 fix mounting of contact0.d81 and updating BAM after record allocate
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2025-08-03 begin implementing error logging framework to track down bugs
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2025-08-03 thread can now retrieve messages (but message filter/search not working)
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2025-08-04 fix footprint gen >64 pins. Add footprint for TE0725 carrier
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
